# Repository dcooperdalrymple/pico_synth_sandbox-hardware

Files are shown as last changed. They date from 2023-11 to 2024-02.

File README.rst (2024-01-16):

pico_synth_sandbox Hardware
===========================



Raspberry Pi Pico digital synthesizer board with stereo I2S audio (ADC & DAC), stereo omnidirectional MEMS microphones, MIDI i/o, a 16-key capacitive keybed, 1602 display, 2 rotary encoders, and LiPo battery charging and power distribution. Designed for use with CircuitPython and synthio.

.. list-table::

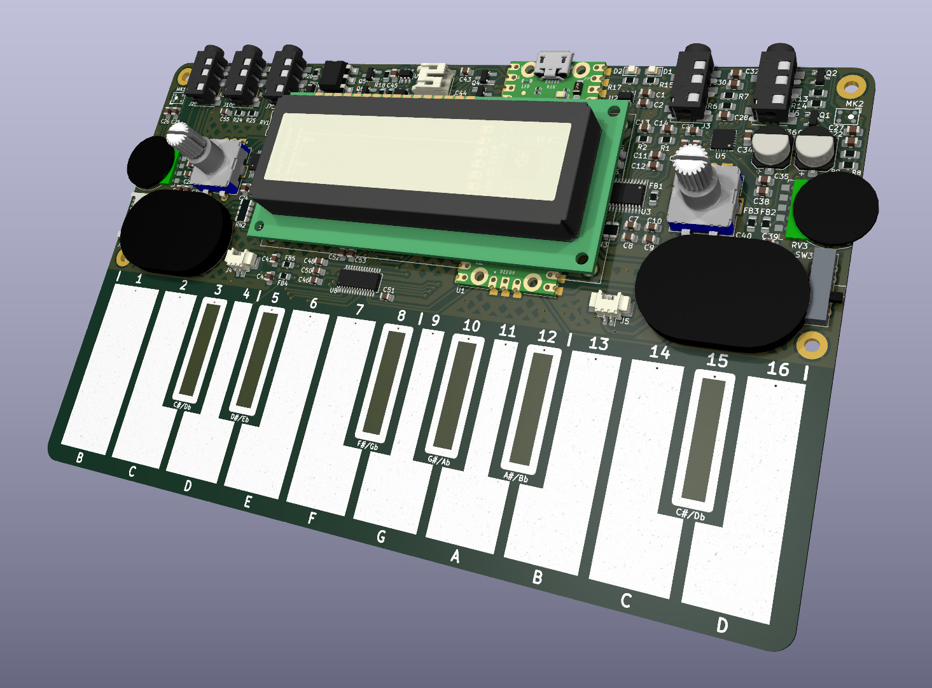
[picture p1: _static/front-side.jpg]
Front view of 3d rendered board
    * - 
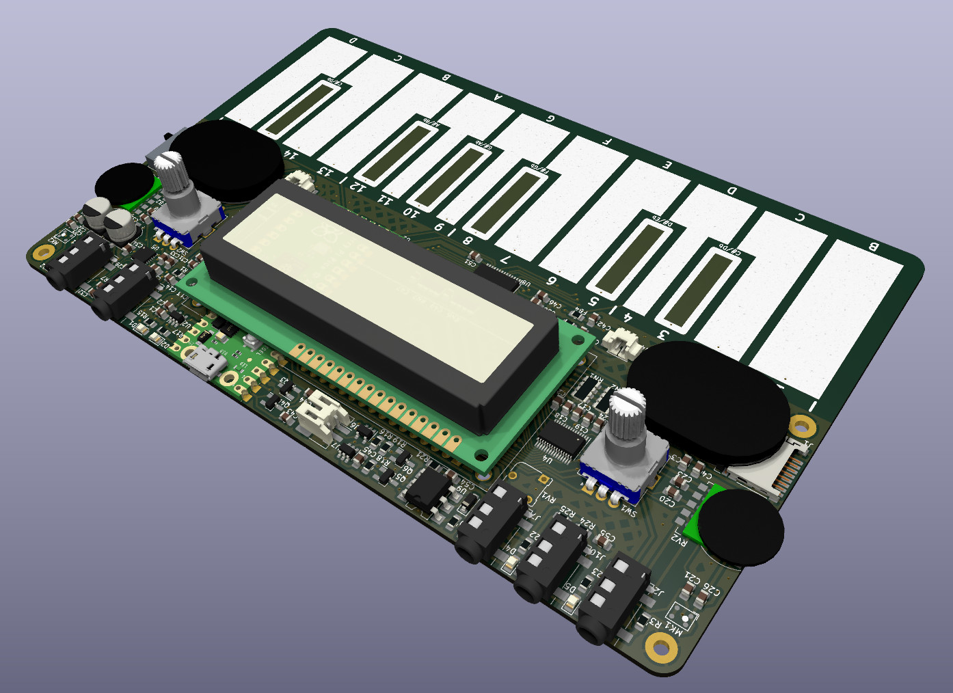
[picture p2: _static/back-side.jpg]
Back view of 3d rendered board
      - 
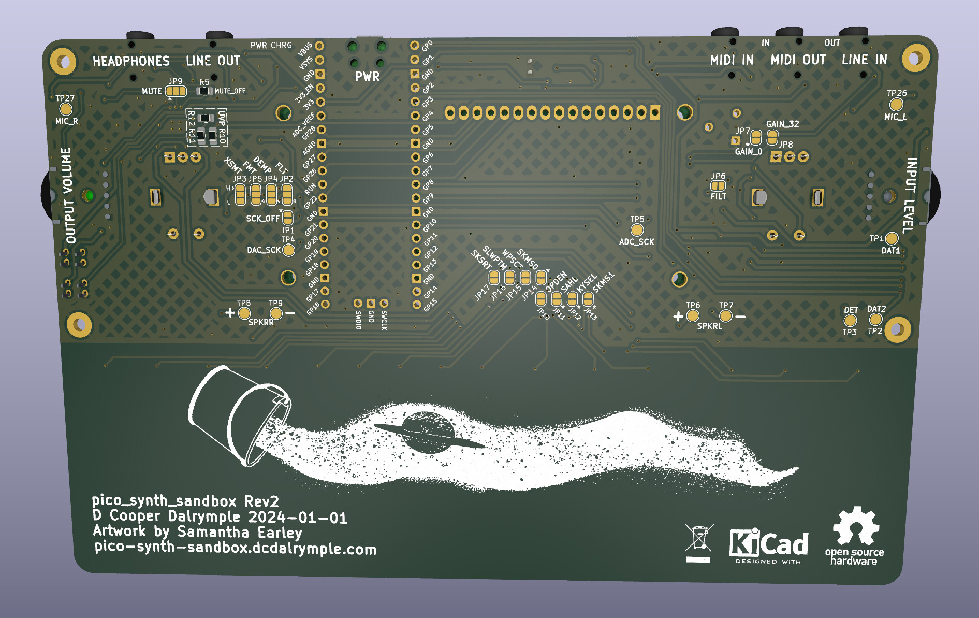
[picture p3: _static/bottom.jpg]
Bottom view of 3d rendered board
      - 

Features
--------

* PCM5102 I2S DAC with line output
* PCM1860 I2S ADC with line and microphone input
* PAM8019 amplifier with stereo class AB headphone and class D speaker output
* LiPo Battery usb charging and power supply controlled by 3v3_enable
* MIDI input and output via MIDI TRS-A 3.5mm jacks (compatible with most adapters)
* Input level potentiometer (line input only)
* Amplifier volume potentiometer (line output not included)
* 16 capacitive sense touch buttons powered by the TTP229-BSF
* 16x2 LCD character display
* 2 rotary encoders with push switches
* Micro SD card storage

Software
--------

CircuitPython Library
~~~~~~~~~~~~~~~~~~~~~

The pico_synth_sandbox is designed for use with CircuitPython and synthio. A specialized library with hardware abstraction and a multitude of additional features for embedded audio synthesis is available in the `pico_synth_sandbox <https://github.com/dcooperdalrymple/pico_synth_sandbox>`_ repository. Library documentation and other resources are available on `Read the Docs <https://pico-synth-sandbox.readthedocs.io/>`_.

CircuitPython Tests
~~~~~~~~~~~~~~~~~~~

A number of hardware tests are available within the ``./tests`` directory to validate the ``pico_synth_sandbox`` hardware using the REPL serial terminal.

RP2040 Pin Assignment
---------------------

Some pins require solder jumper configuration if you do not use the default pin assignment for MIDI & I2S.

.. list-table::
    :header-rows: 1

    * - Pin Reference
      - Assignment
      - Direction
      - Function

    * - GP0
      - SD Card RX
      - Input
      - SPI0
    * - GP1
      - SD Card CS
      - Output
      - SPI0
    * - GP2
      - SD Card SCK
      - Output
      - SPI0
    * - GP3
      - SD Card TX
      - Output
      - SPI0
    * - GP4
      - MIDITX
      - Output
      - UART1
    * - GP5
      - MIDIRX
      - Input
      - UART1
    * - GP6
      - 1602 Enable
      - Output
      - GPIO
    * - GP7
      - 1602 Reset
      - Output
      - GPIO
    * - GP8
      - ADC Serial Clock
      - Output
      - I2S
    * - GP9
      - ADC Word Select
      - Output
      - I2S
    * - GP10
      - ADC Serial Data
      - Input
      - I2S
    * - GP11
      - Encoder 1 A
      - Input
      - GPIO
    * - GP12
      - Encoder 1 B
      - Input
      - GPIO
    * - GP13
      - Encoder 1 Switch
      - Input
      - GPIO
    * - GP14
      - TTP229 Serial Data
      - Input
      - GPIO
    * - GP15
      - TTP229 Serial Clock
      - Output
      - GPIO
    * - GP16
      - Encoder 2 A
      - Input
      - GPIO
    * - GP17
      - Encoder 2 B
      - Input
      - GPIO
    * - GP18
      - Encoder 2 Switch
      - Input
      - GPIO
    * - GP19
      - DAC Serial Clock
      - Output
      - I2S
    * - GP20
      - DAC Word Select
      - Output
      - I2S
    * - GP21
      - DAC Serial Data
      - Output
      - I2S
    * - GP22
      - 1602 D4
      - Output
      - GPIO
    * - GP26
      - 1602 D5
      - Output
      - GPIO
    * - GP27
      - 1602 D6
      - Output
      - GPIO
    * - GP28
      - 1602 D7
      - Output
      - GPIO

Schematic
---------

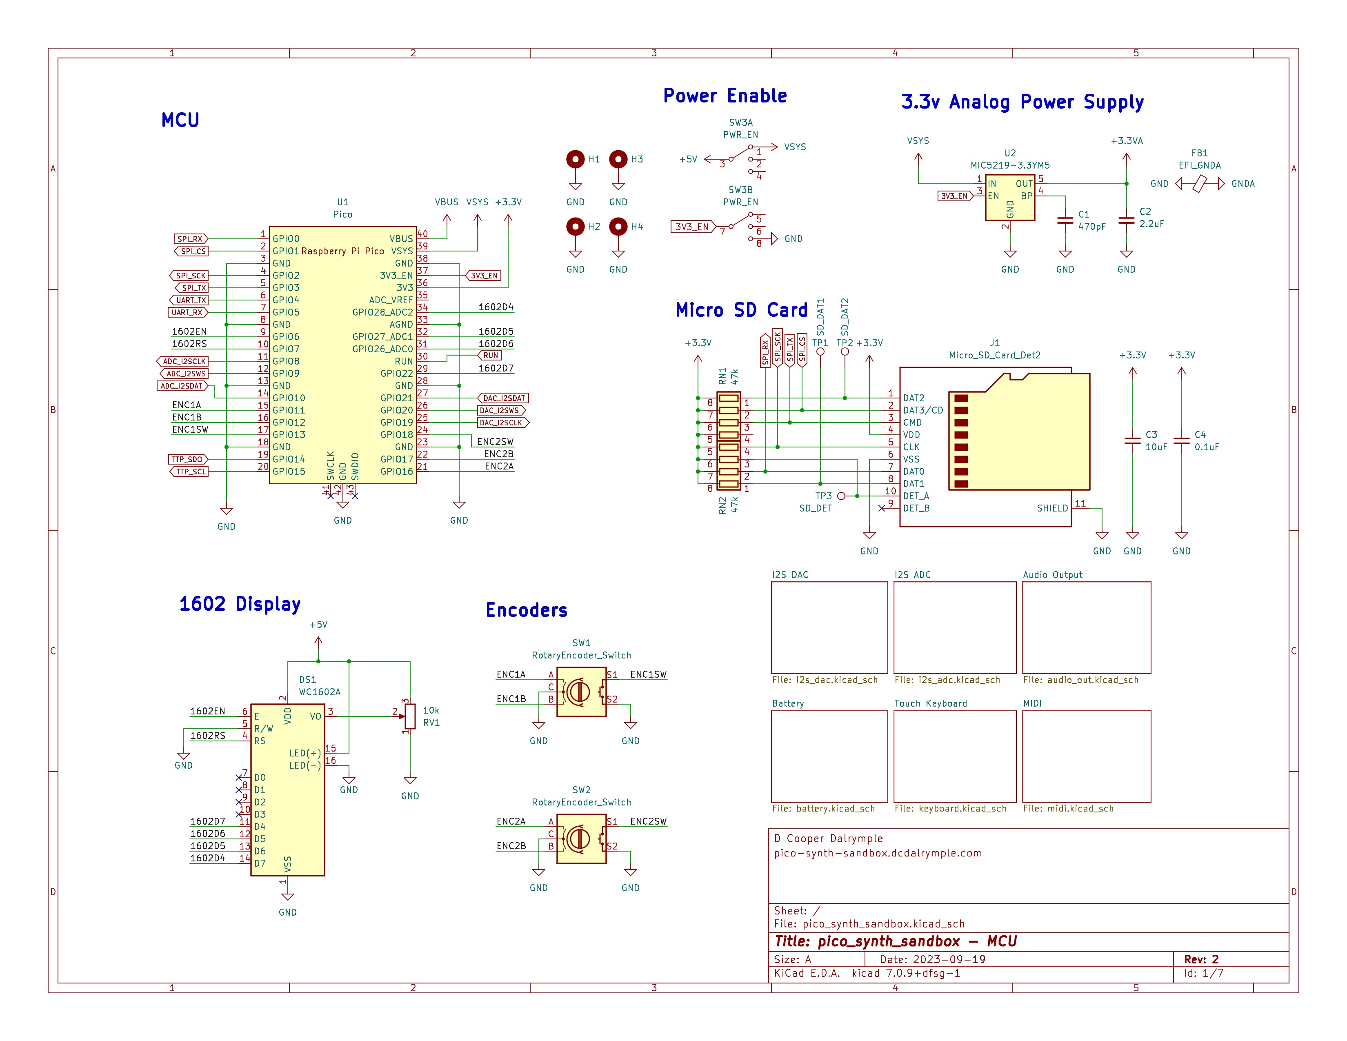
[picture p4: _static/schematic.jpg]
Hardware schematic of pico_synth_sandbox device


Attribution
-----------

* Project inspired by `todbot/pico_test_synth <https://github.com/todbot/pico_test_synth>`_

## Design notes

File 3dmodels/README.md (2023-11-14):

# KiCAD 3D Models
Most models were sourced from GrabCAD and weren't given proper attribution. These files were for temporary use in order to generate preview renders. They will likely be removed in a future update.

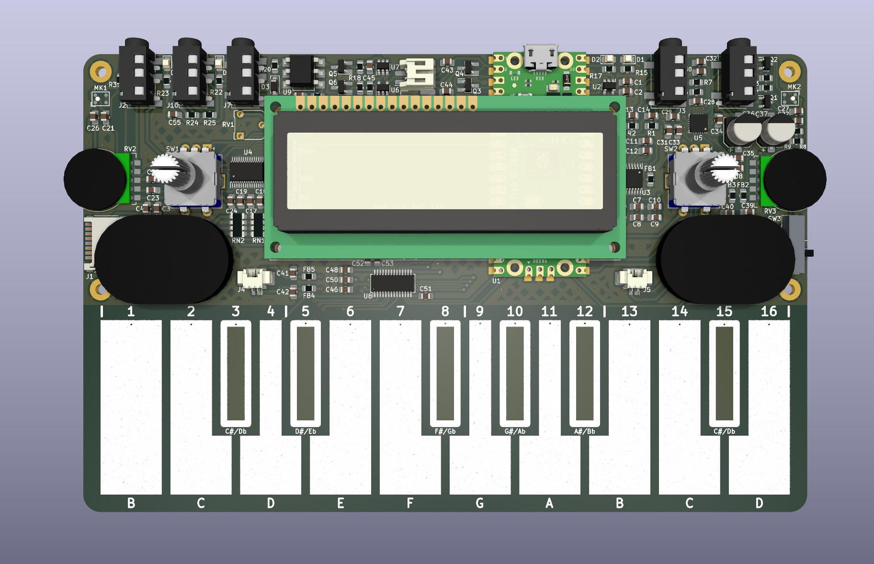
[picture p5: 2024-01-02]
_static/top.jpg

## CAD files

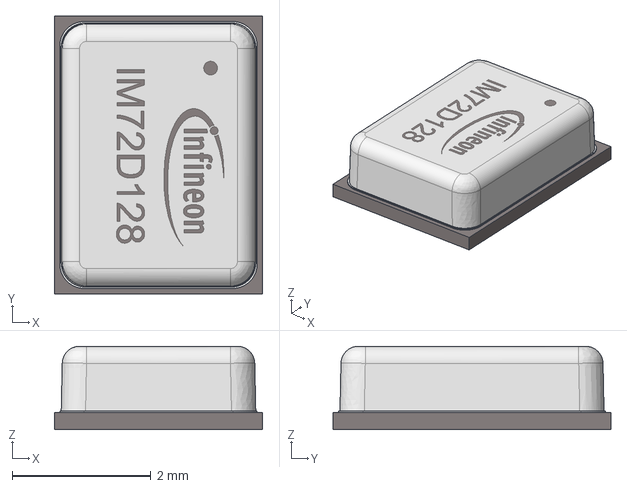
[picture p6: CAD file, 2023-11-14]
3dmodels/digital-microphone-1/IM72D128 MEMS microphone.stp
3.00 x 4.00 x 1.20 mm

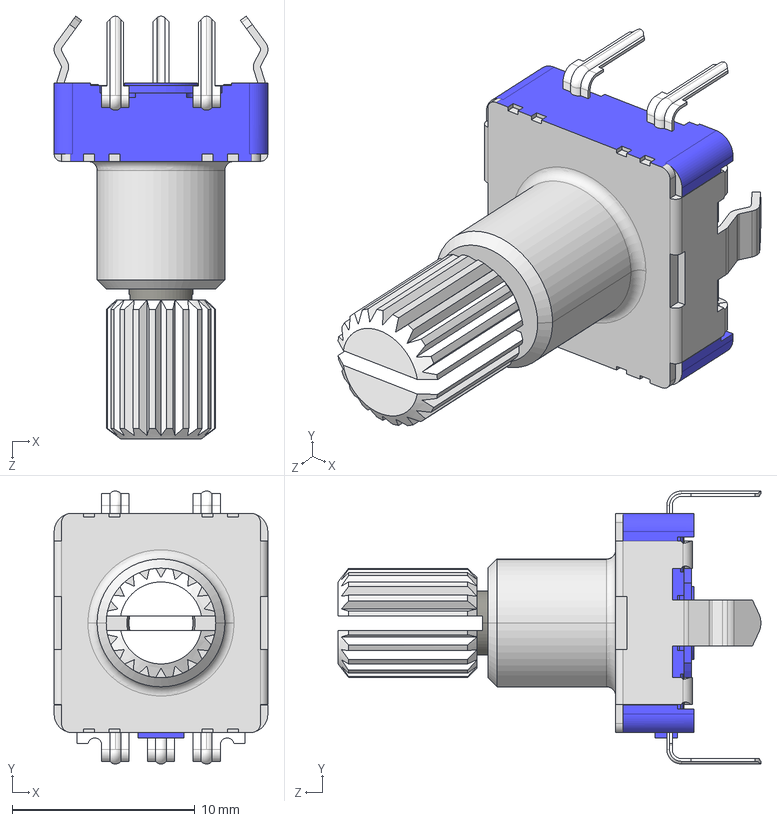
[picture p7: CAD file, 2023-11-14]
3dmodels/ec11-encoder/EC11 Rotary Encoder Dode Switch-15mm .STEP
11.7 x 15.0 x 23.2 mm

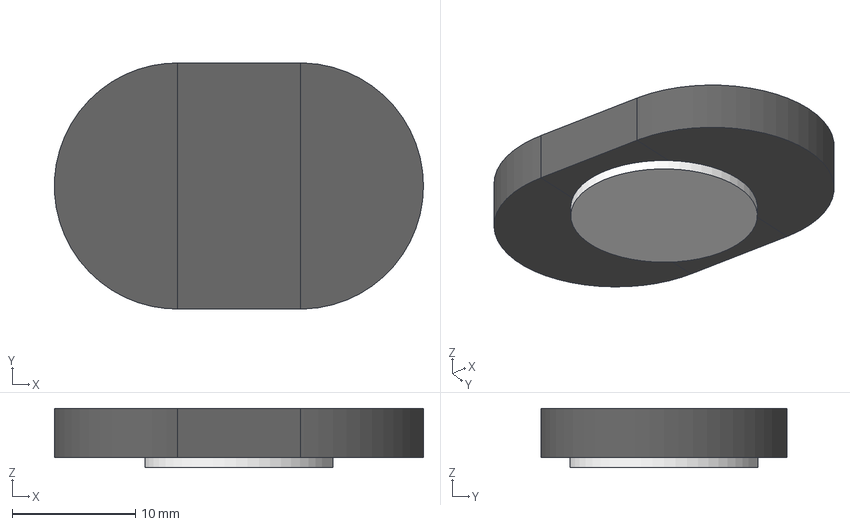
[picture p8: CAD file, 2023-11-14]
3dmodels/mini-oval-speaker-with-short-wires-8-ohm-1-watt/mini-oval-speaker.step
30.0 x 20.0 x 4.80 mm

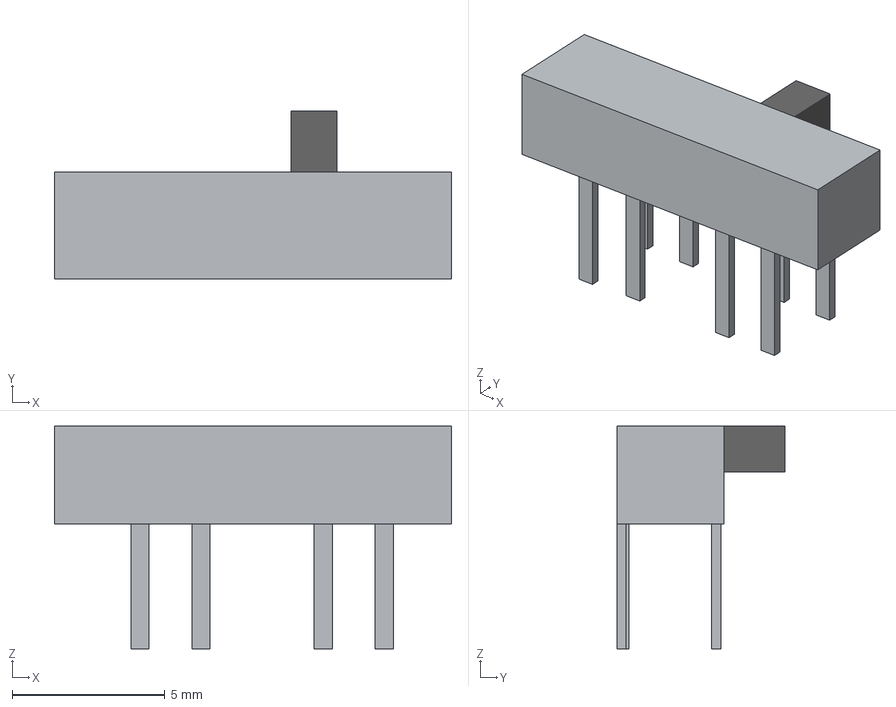
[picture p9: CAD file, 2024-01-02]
3dmodels/MK-23D38/MK-23D38.step
13.0 x 5.50 x 7.30 mm

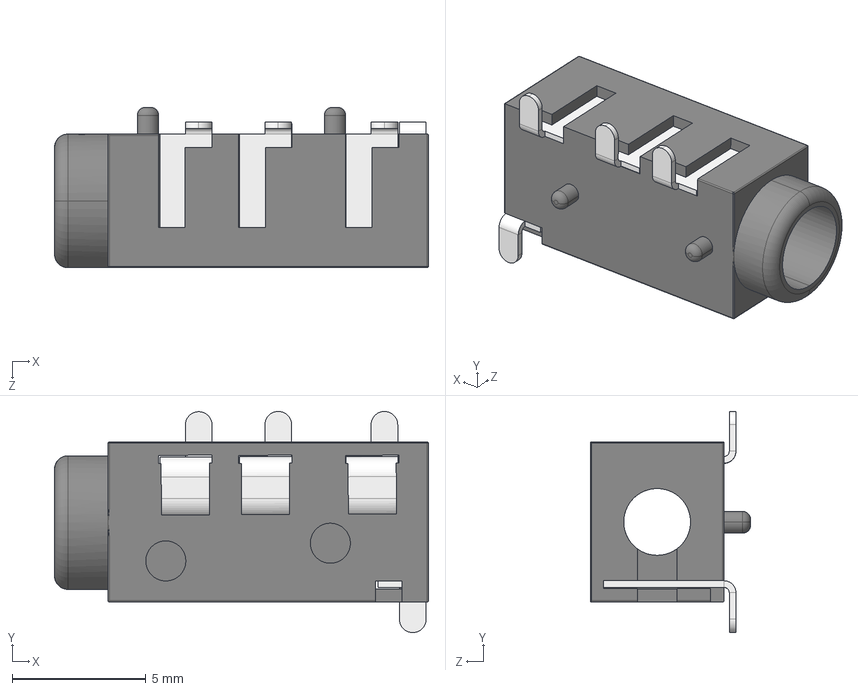
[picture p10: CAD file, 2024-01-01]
3dmodels/PJ320D/PJ320D.STEP
14.0 x 8.28 x 6.00 mm
PJ320A
PJ320D-Pin x 3
PJ320D-Pin-B

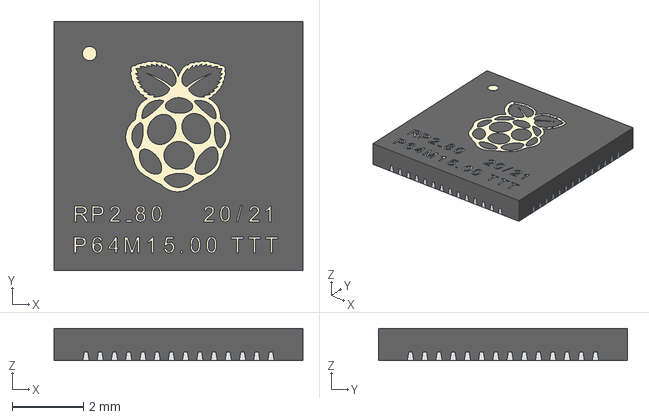
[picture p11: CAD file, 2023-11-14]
3dmodels/raspberry-pi-pico/RP2040.step
7.00 x 7.00 x 0.91 mm

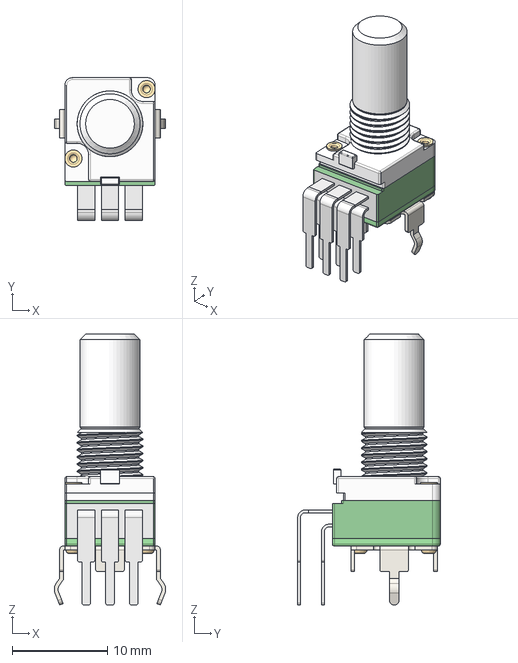
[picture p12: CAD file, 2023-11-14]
3dmodels/RD902F-40-00D/RD902F-40-00D.stp
11.7 x 15.0 x 28.5 mm

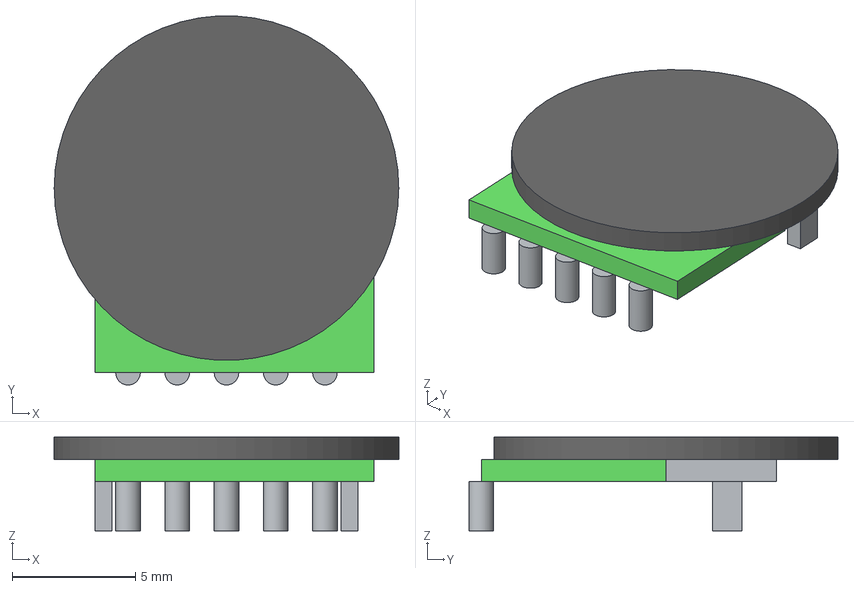
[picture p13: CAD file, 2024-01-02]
3dmodels/RK10J12R0A0B/RK10J12R0A0B.step
14.0 x 15.0 x 3.80 mm

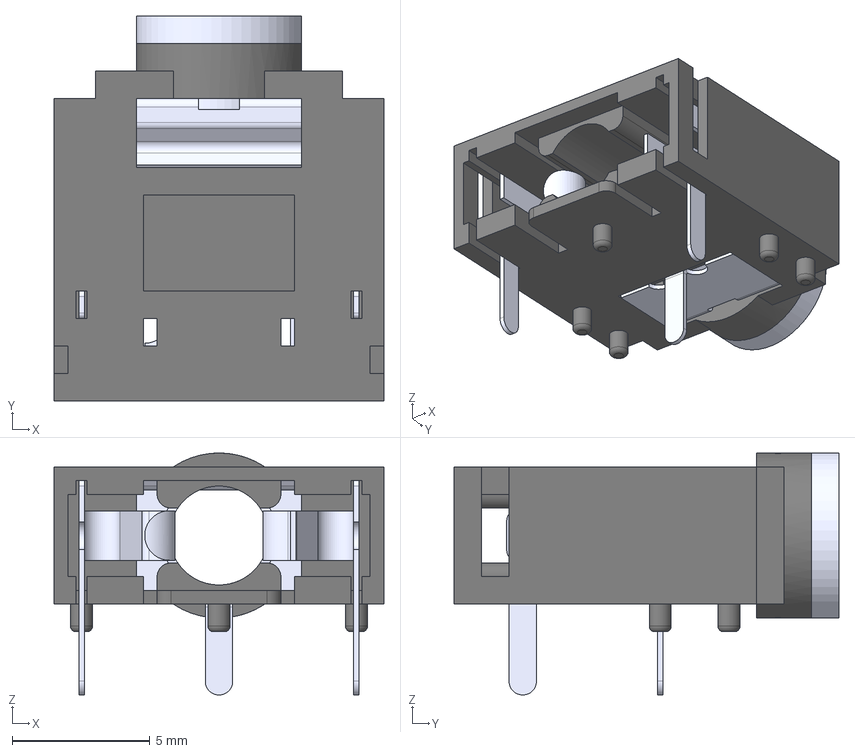
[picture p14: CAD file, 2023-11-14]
3dmodels/SJ1-3525N/ST-111.step
12.0 x 14.0 x 8.80 mm

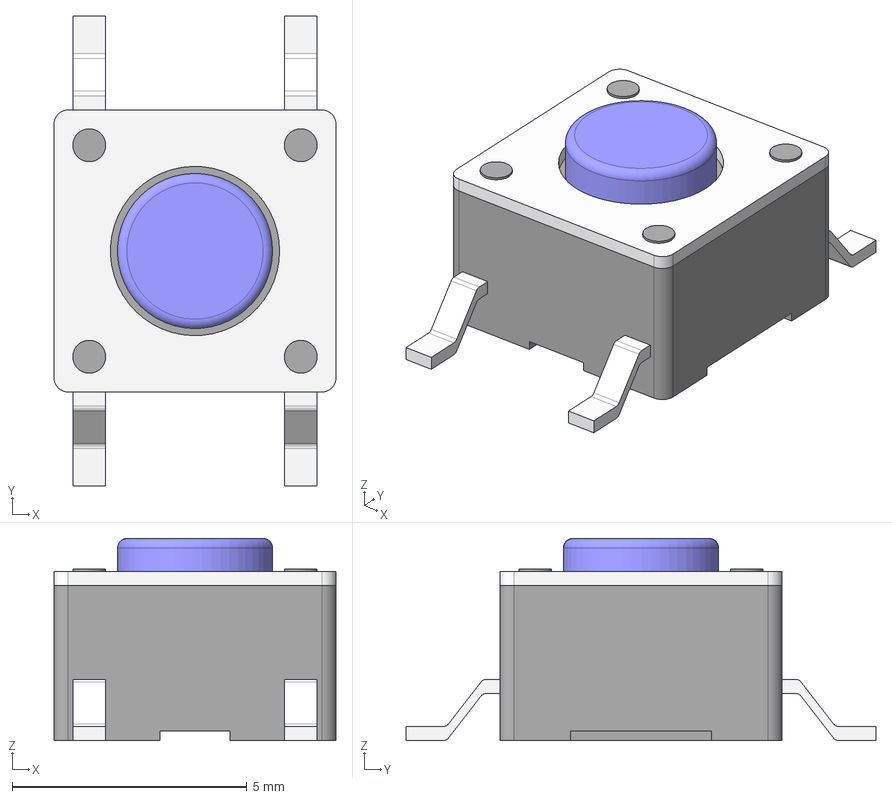
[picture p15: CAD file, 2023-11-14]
3dmodels/smd-button/LL3301_SMT Button.FCStd
6.00 x 10.0 x 4.30 mm
TopPlate
Plunger
Pins

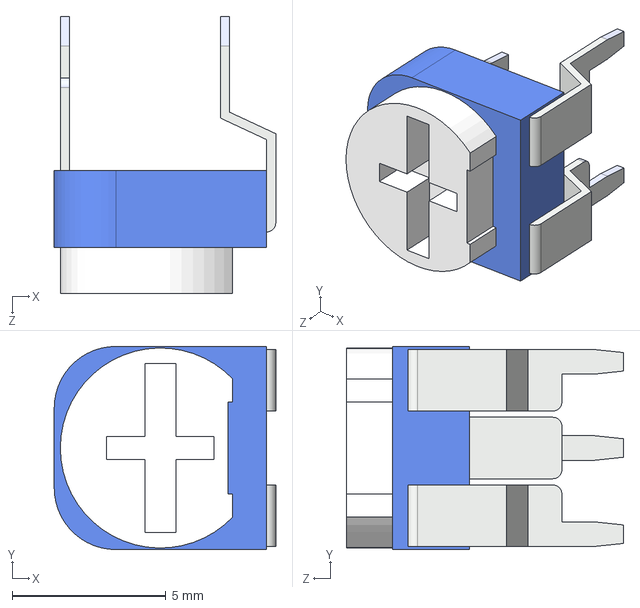
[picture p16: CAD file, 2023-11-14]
3dmodels/trimpot/Potentiometer Blue.STEP
7.20 x 6.60 x 9.00 mm

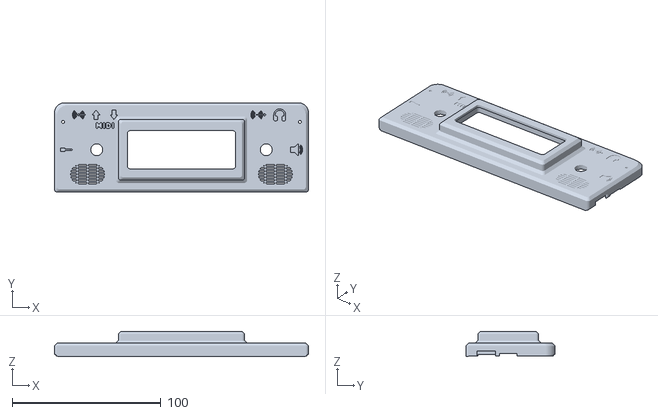
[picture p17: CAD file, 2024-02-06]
case/rev2/pico_synth_sandbox-Rev2-Top.stl
171.0 x 60.0 x 17.1

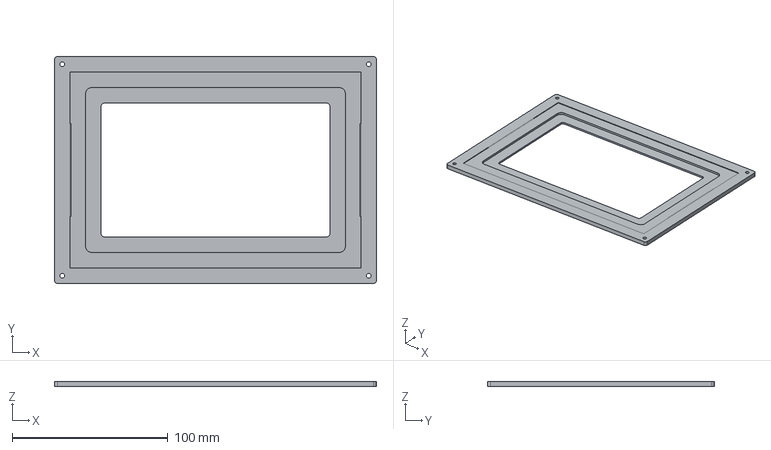
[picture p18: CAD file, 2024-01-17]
stencil-jig/pico_synth_sandbox-StencilJig.FCStd
207.0 x 146.0 x 3.50 mm

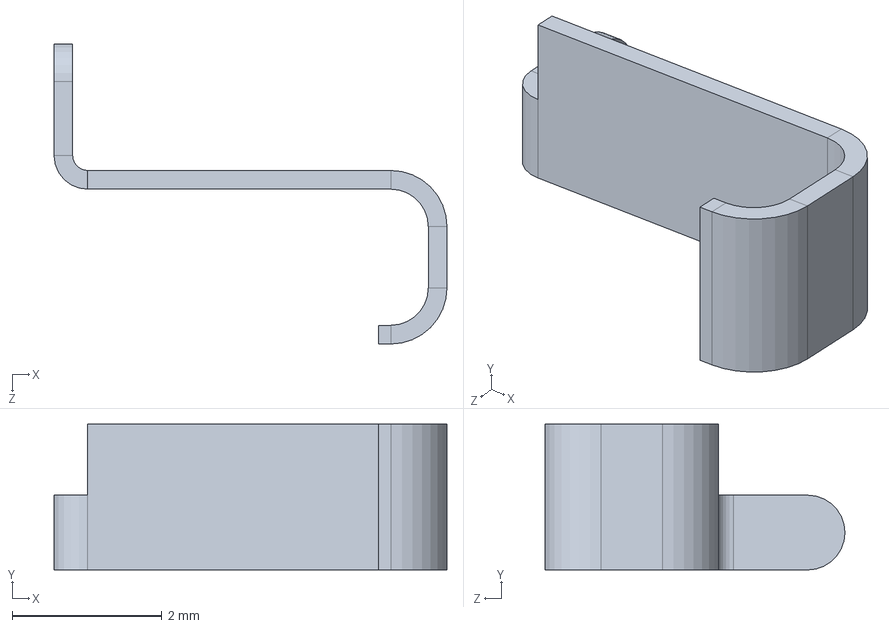
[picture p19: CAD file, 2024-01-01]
3dmodels/PJ320D/PJ320D-Pin.SLDPRT
5.25 x 1.95 x 4.01 mm

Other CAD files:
3dmodels/raspberry-pi-pico/RT6150B-33GQW.step
3dmodels/SJ1-3525N/ST-212.step
3dmodels/smd-button/LL3301_SMD_Button.step
case/rev2/pico_synth_sandbox-Rev2-Bottom.stl
3dmodels/MK-23D38/MK-23D38.FCStd
3dmodels/MK-23D38/MK-23D38.stl
3dmodels/PJ320D/PJ320A.SLDPRT
3dmodels/PJ320D/PJ320D-Pin-B.SLDPRT
3dmodels/PJ320D/PJ320D.SLDASM
3dmodels/RD902F-40-00D/RD902F-40-00D.f3d
3dmodels/RK10J12R0A0B/RK10J12R0A0B.FCStd
3dmodels/RK10J12R0A0B/RK10J12R0A0B.stl
3dmodels/mini-oval-speaker-with-short-wires-8-ohm-1-watt/mini-oval-speaker.FCStd
3dmodels/raspberry-pi-pico/C0603.step
3dmodels/raspberry-pi-pico/C1005.step
3dmodels/raspberry-pi-pico/C2012.step
3dmodels/raspberry-pi-pico/CircuitBoard_Raspberry Pi Pico.step
3dmodels/raspberry-pi-pico/CrystalUnit.step
3dmodels/raspberry-pi-pico/Inductor.step
3dmodels/raspberry-pi-pico/LED1608_t4.step
3dmodels/raspberry-pi-pico/R0603.step
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

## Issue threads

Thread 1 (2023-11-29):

Website is not working

andypiper, 2023-11-29:
Raising an issue here in an effort to let you know that https://pico-synth-sandbox.dcdalrymple.com/ is currently reporting a WordPress error (and the project has just been shared on the Make magazine news feed, so I’m likely not the only one hitting the issue…)

looking forward to learning more about the board when the site is back!

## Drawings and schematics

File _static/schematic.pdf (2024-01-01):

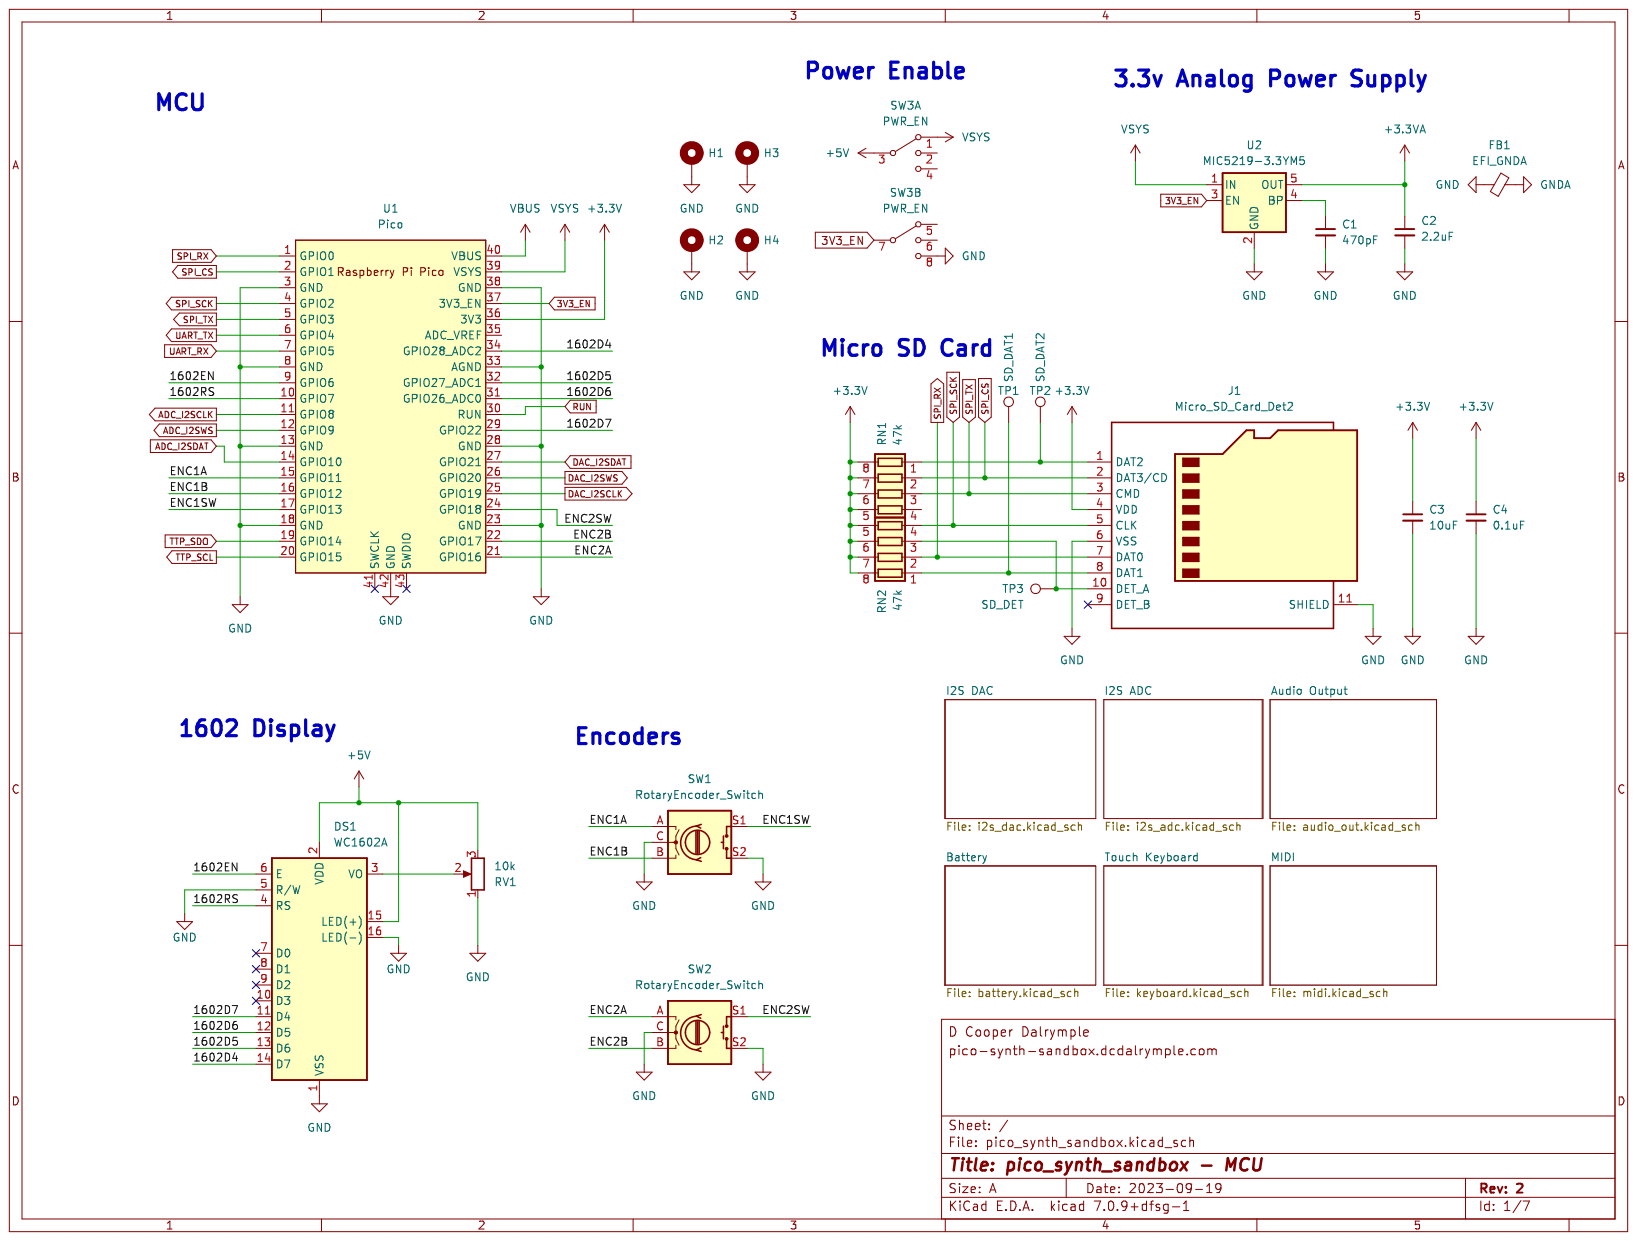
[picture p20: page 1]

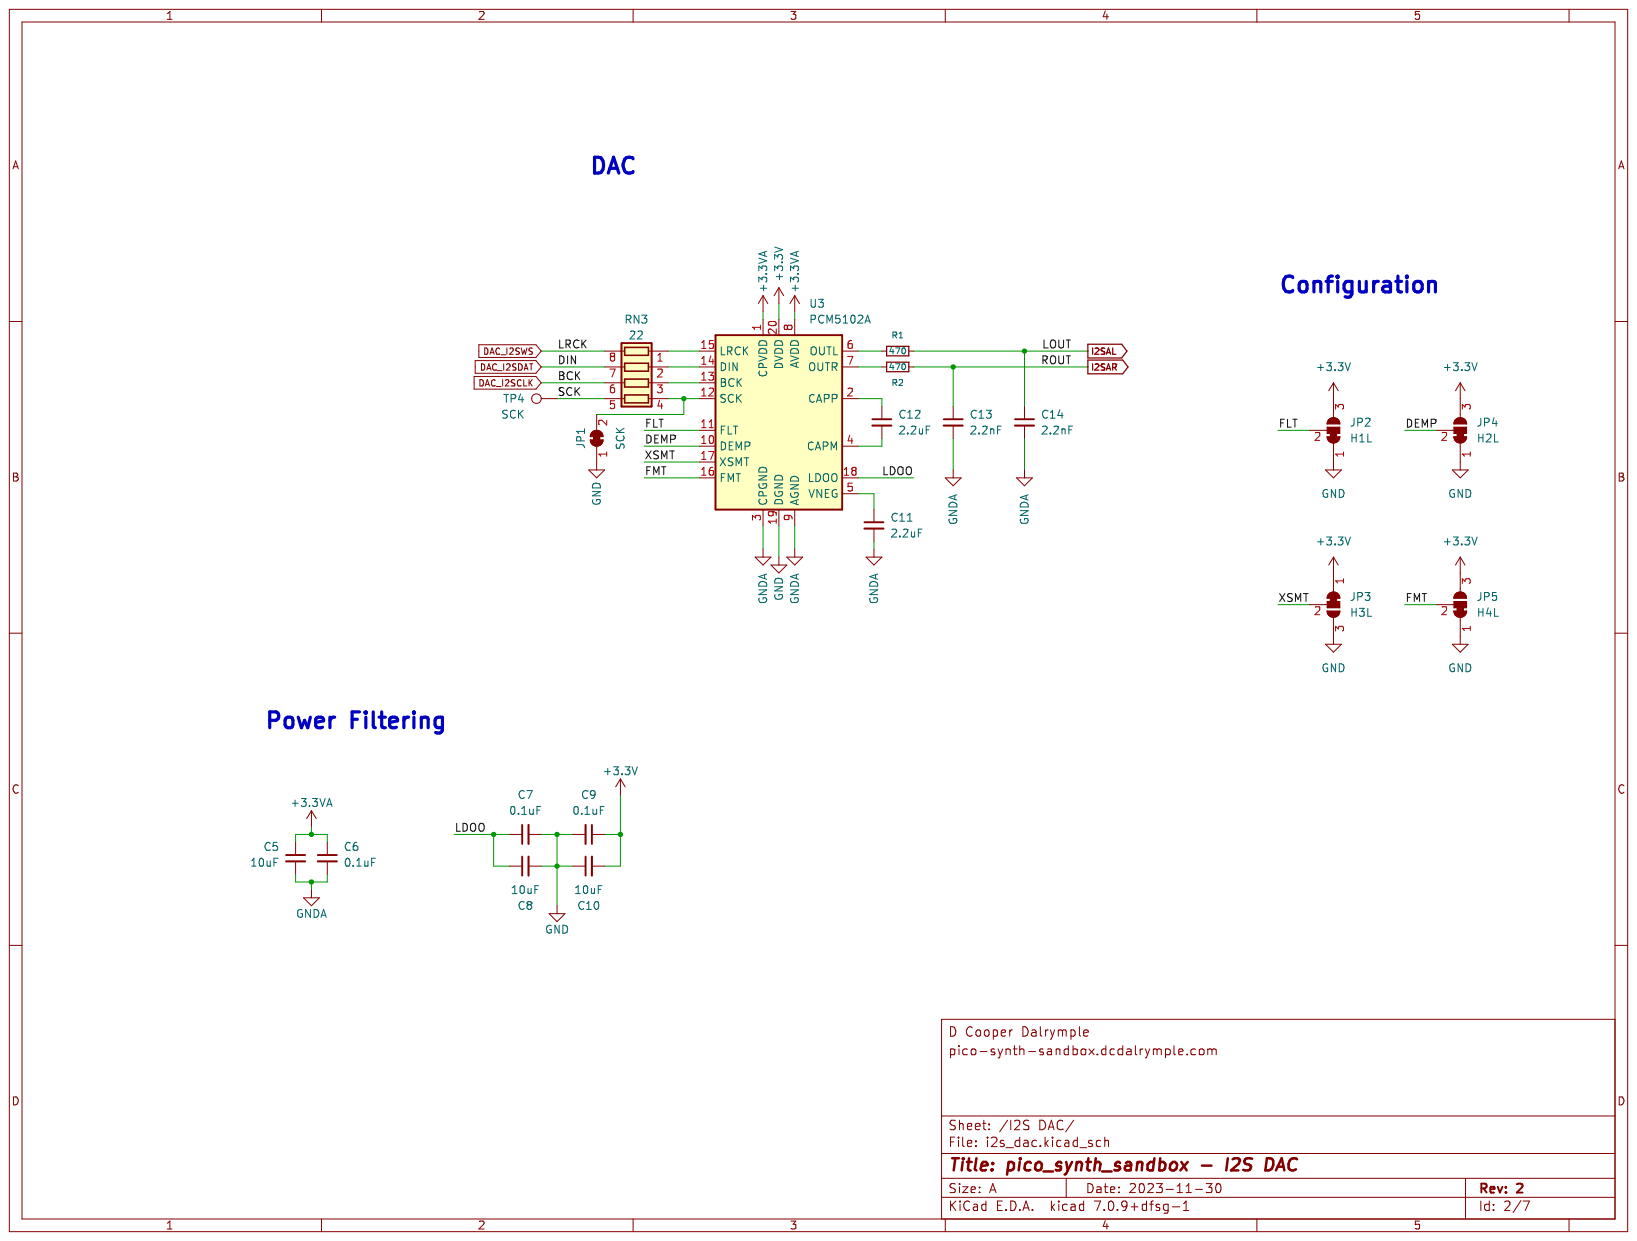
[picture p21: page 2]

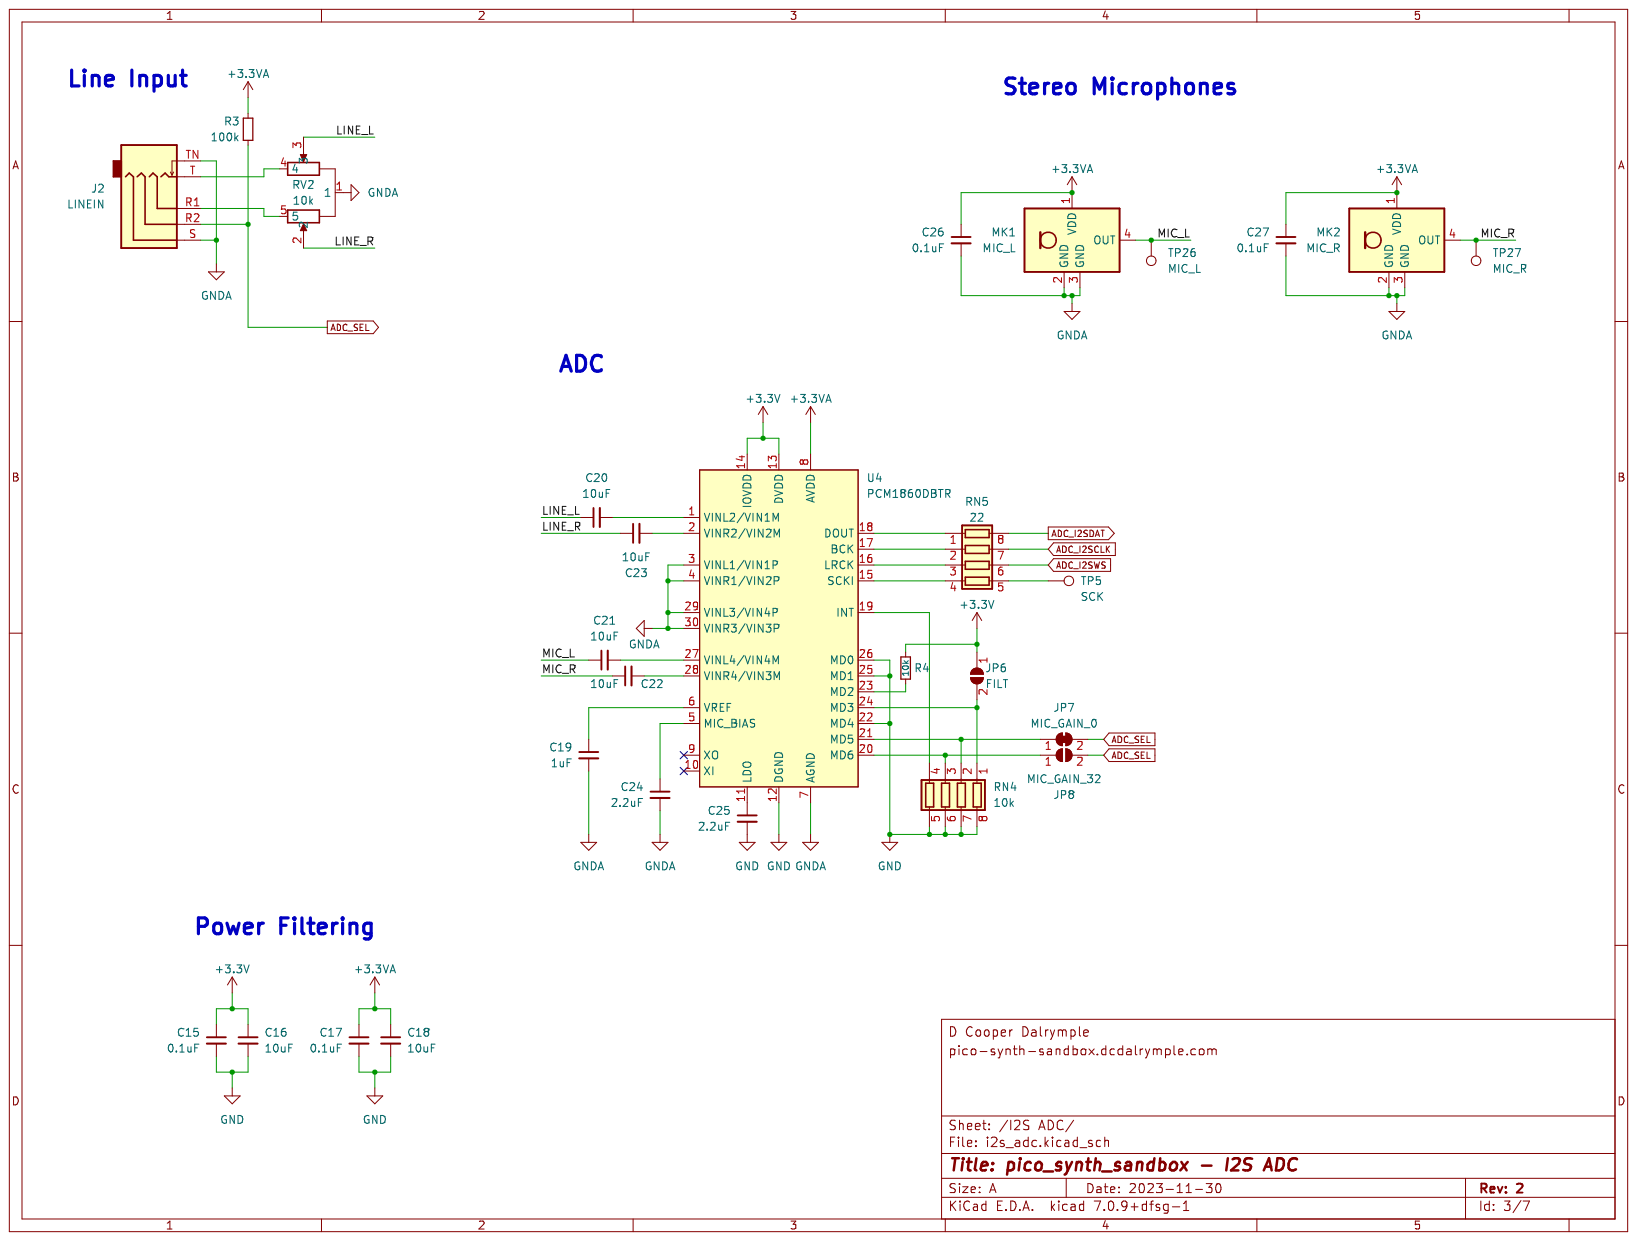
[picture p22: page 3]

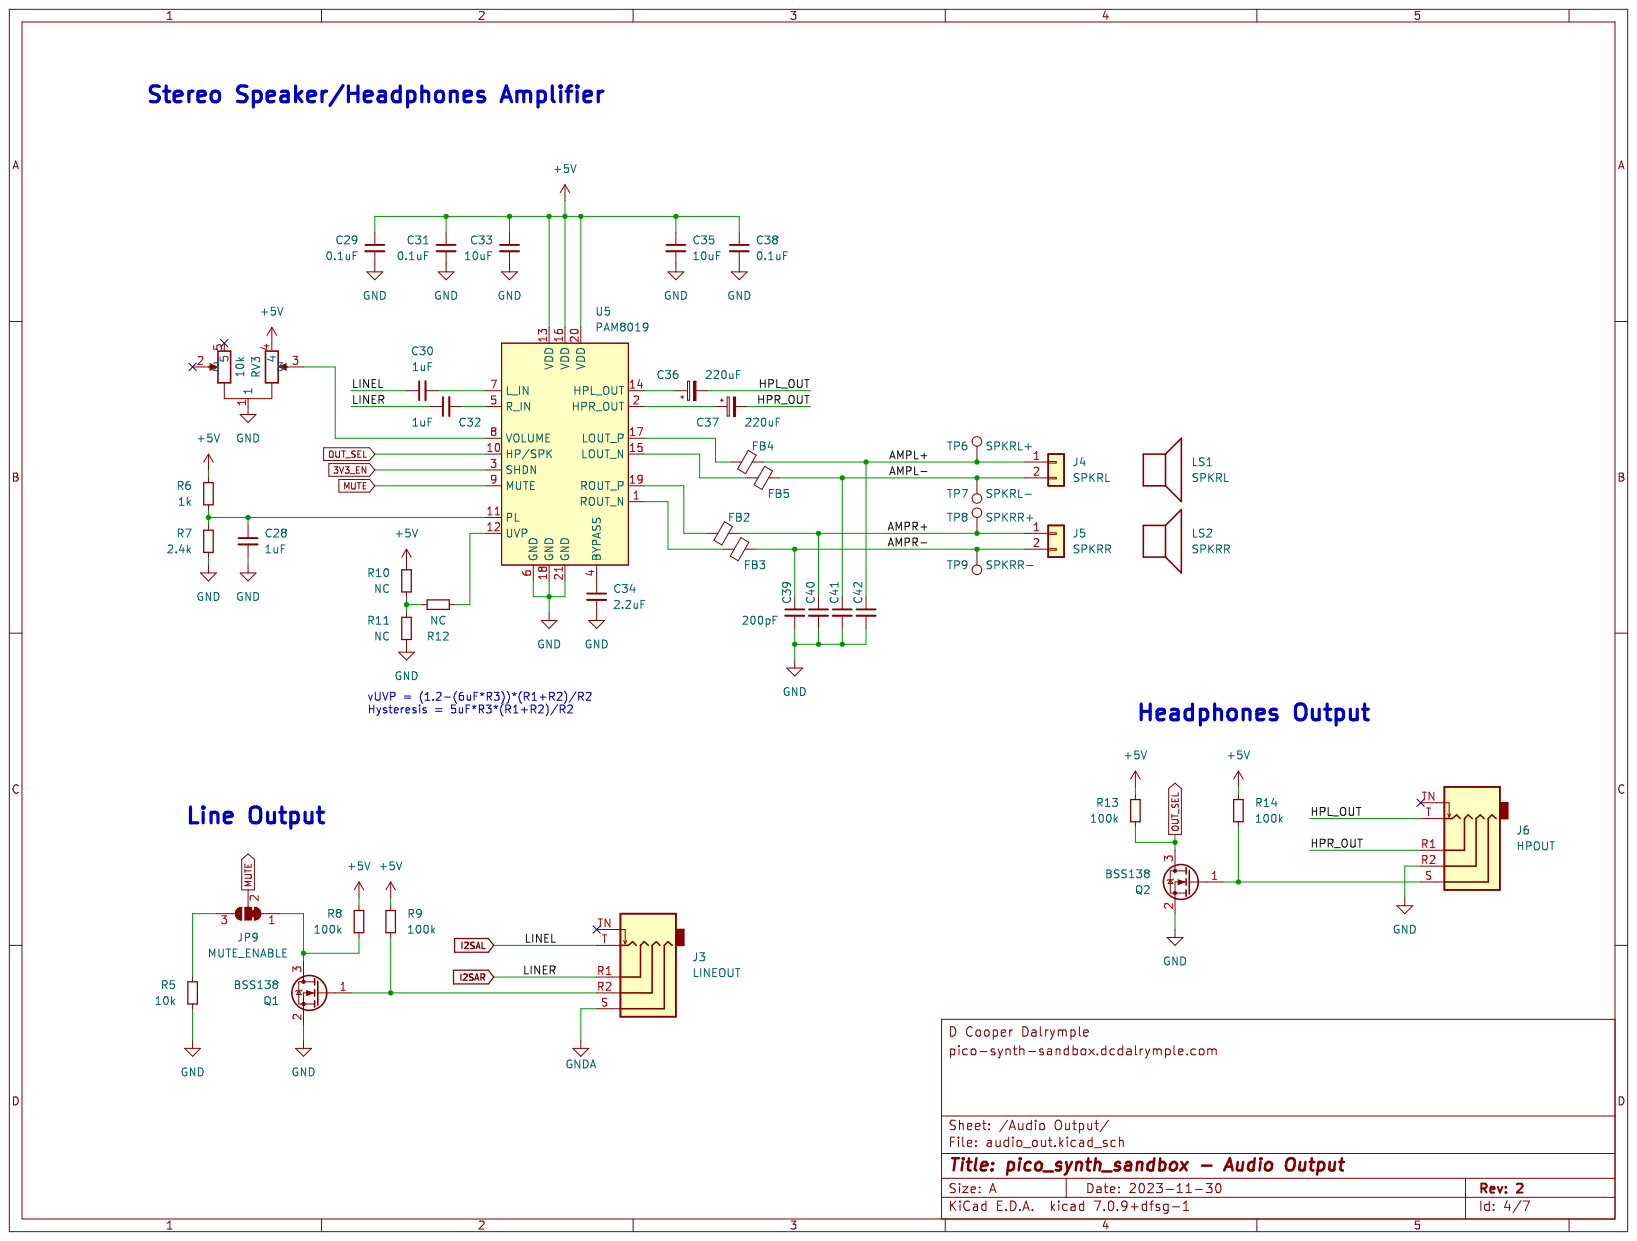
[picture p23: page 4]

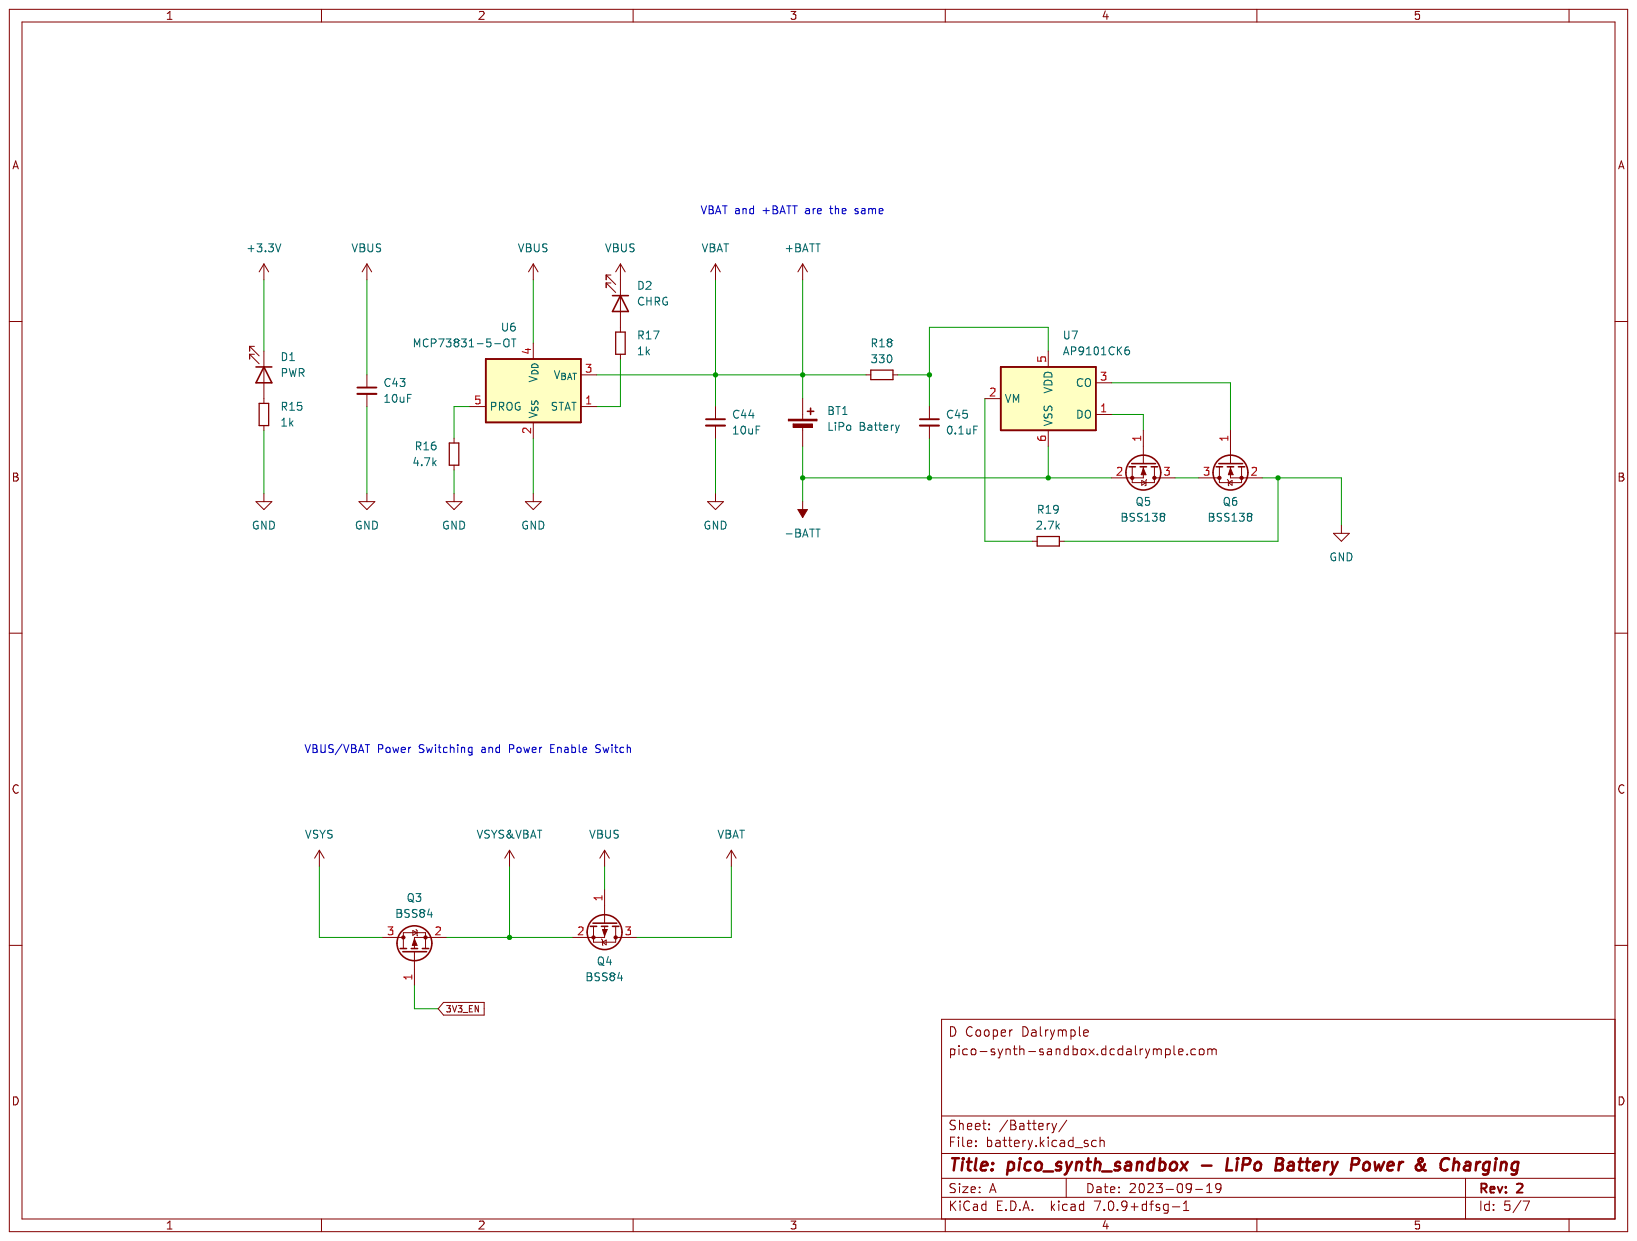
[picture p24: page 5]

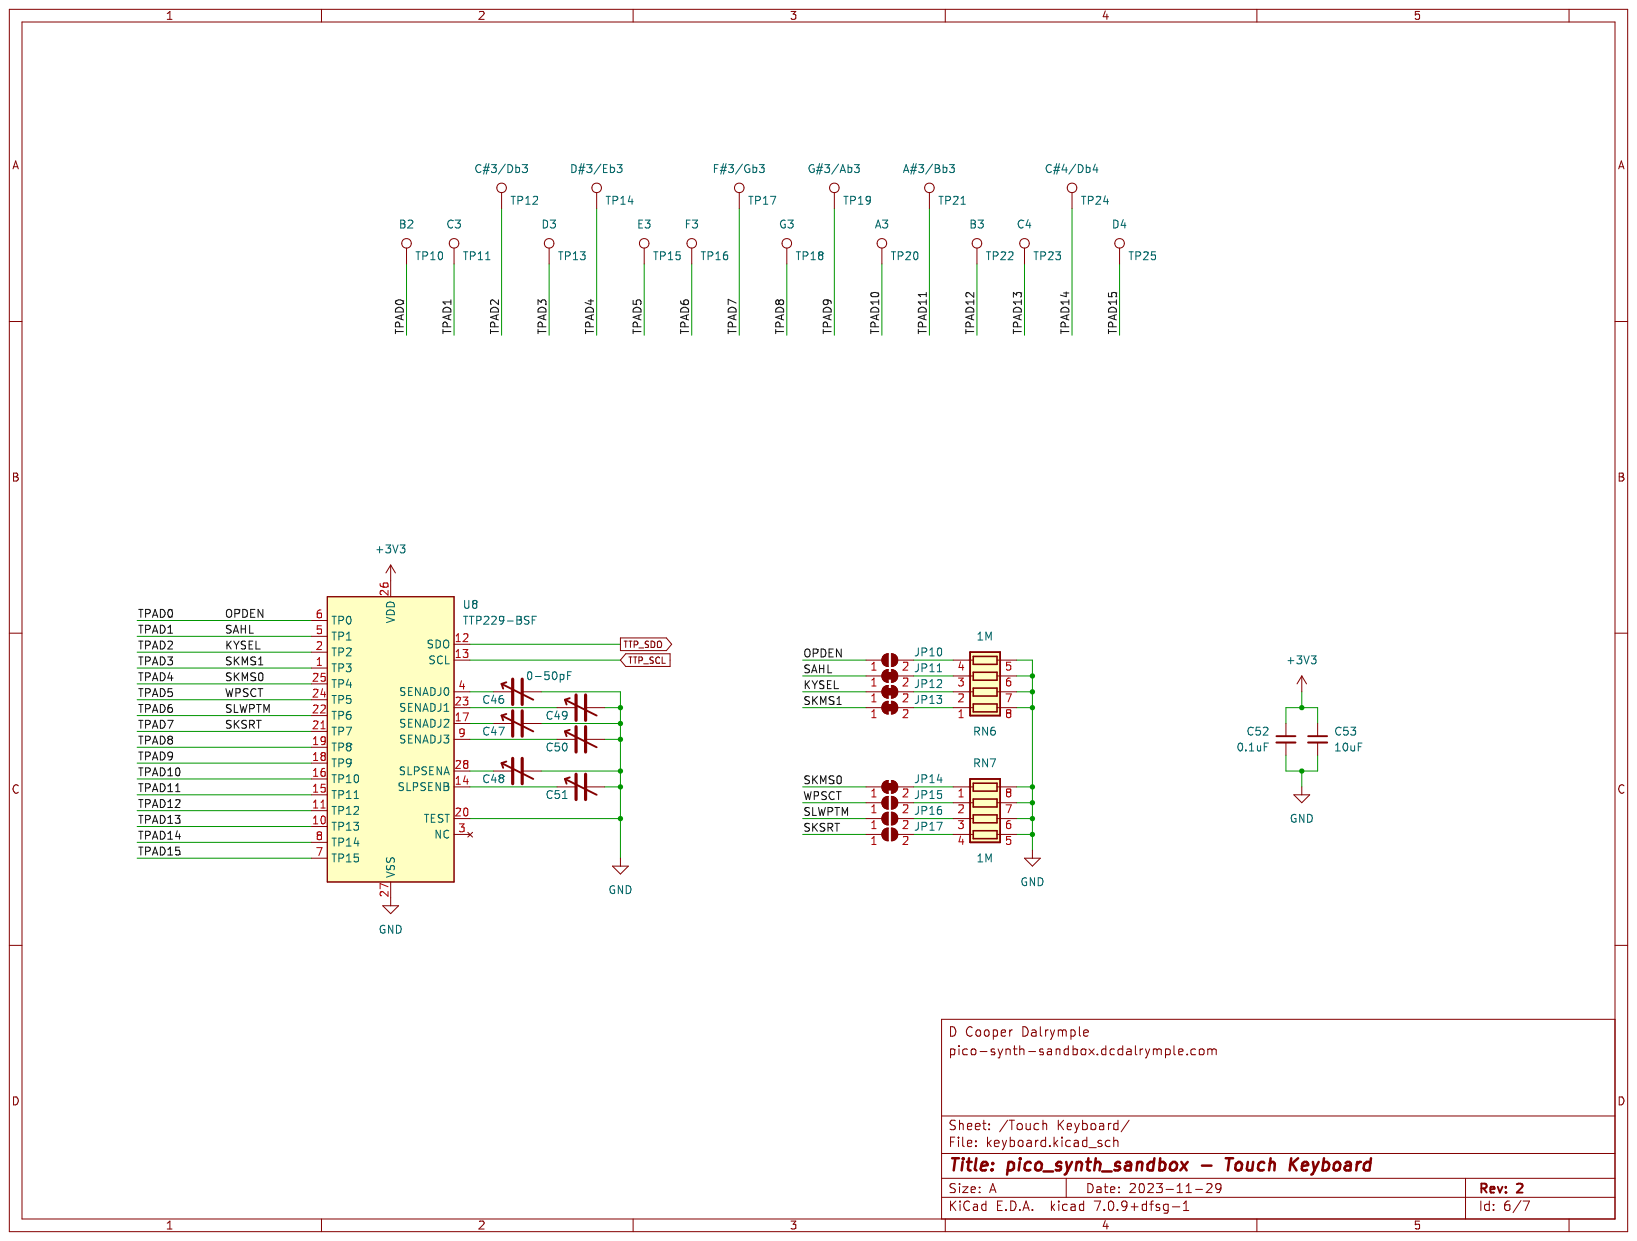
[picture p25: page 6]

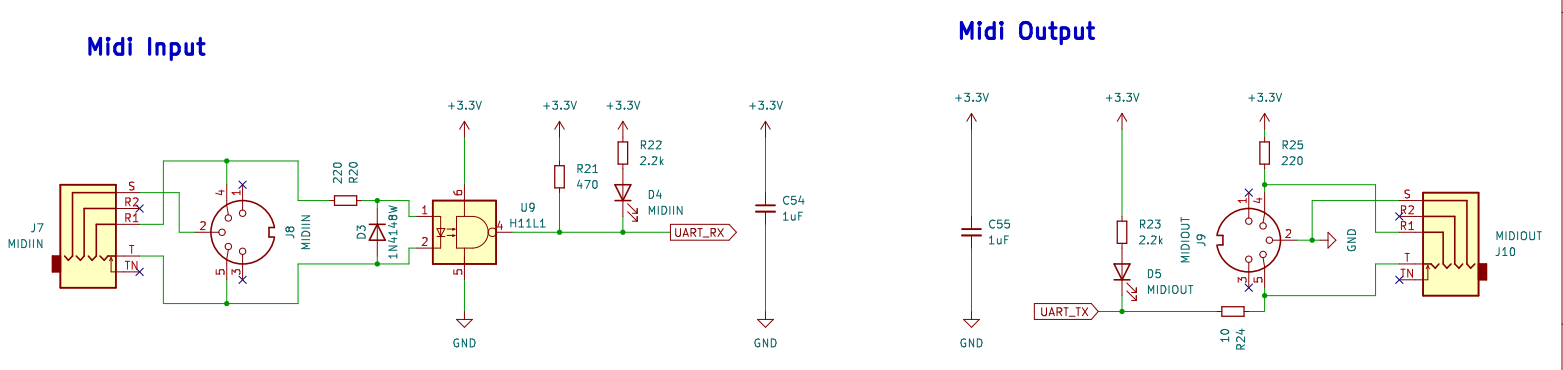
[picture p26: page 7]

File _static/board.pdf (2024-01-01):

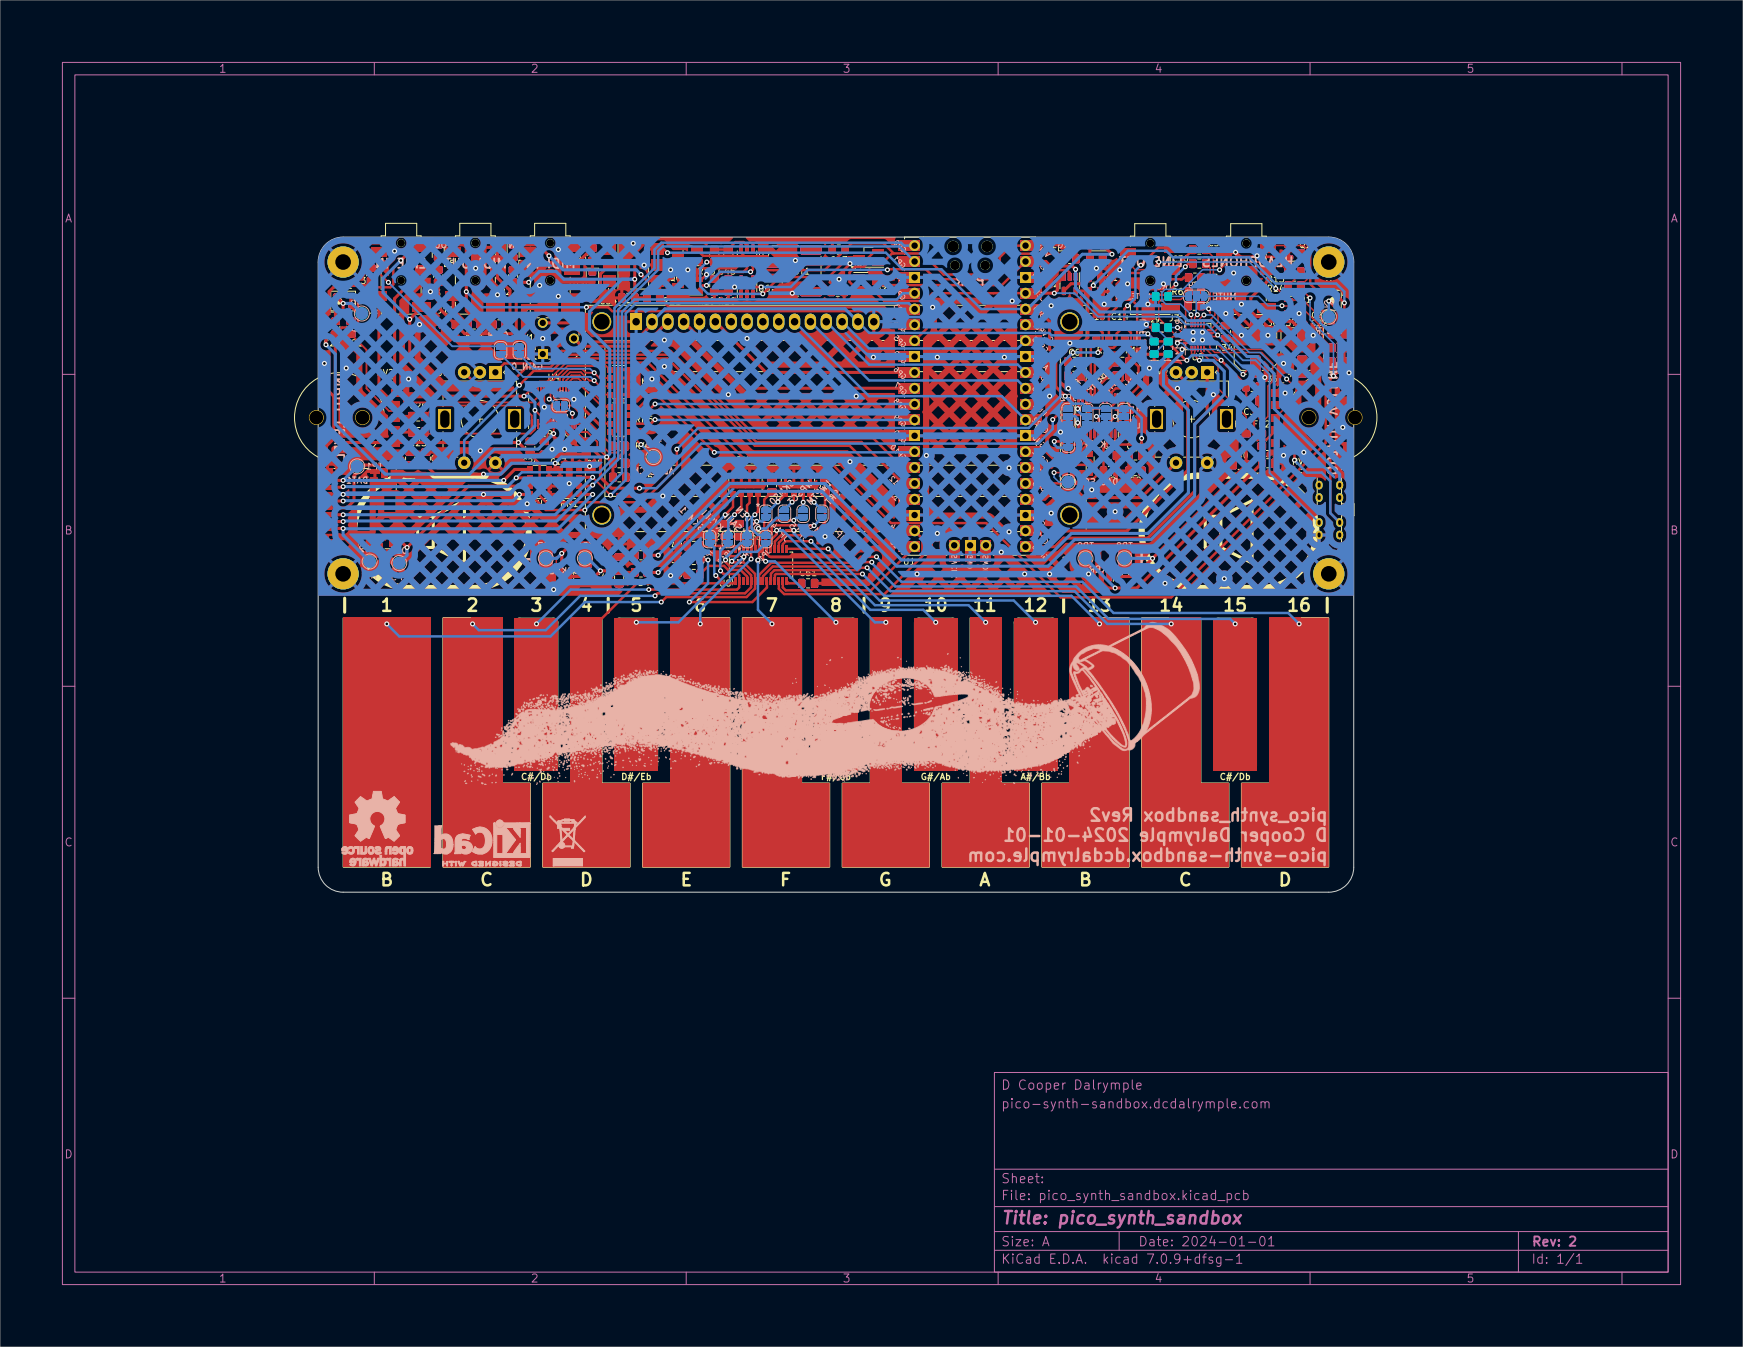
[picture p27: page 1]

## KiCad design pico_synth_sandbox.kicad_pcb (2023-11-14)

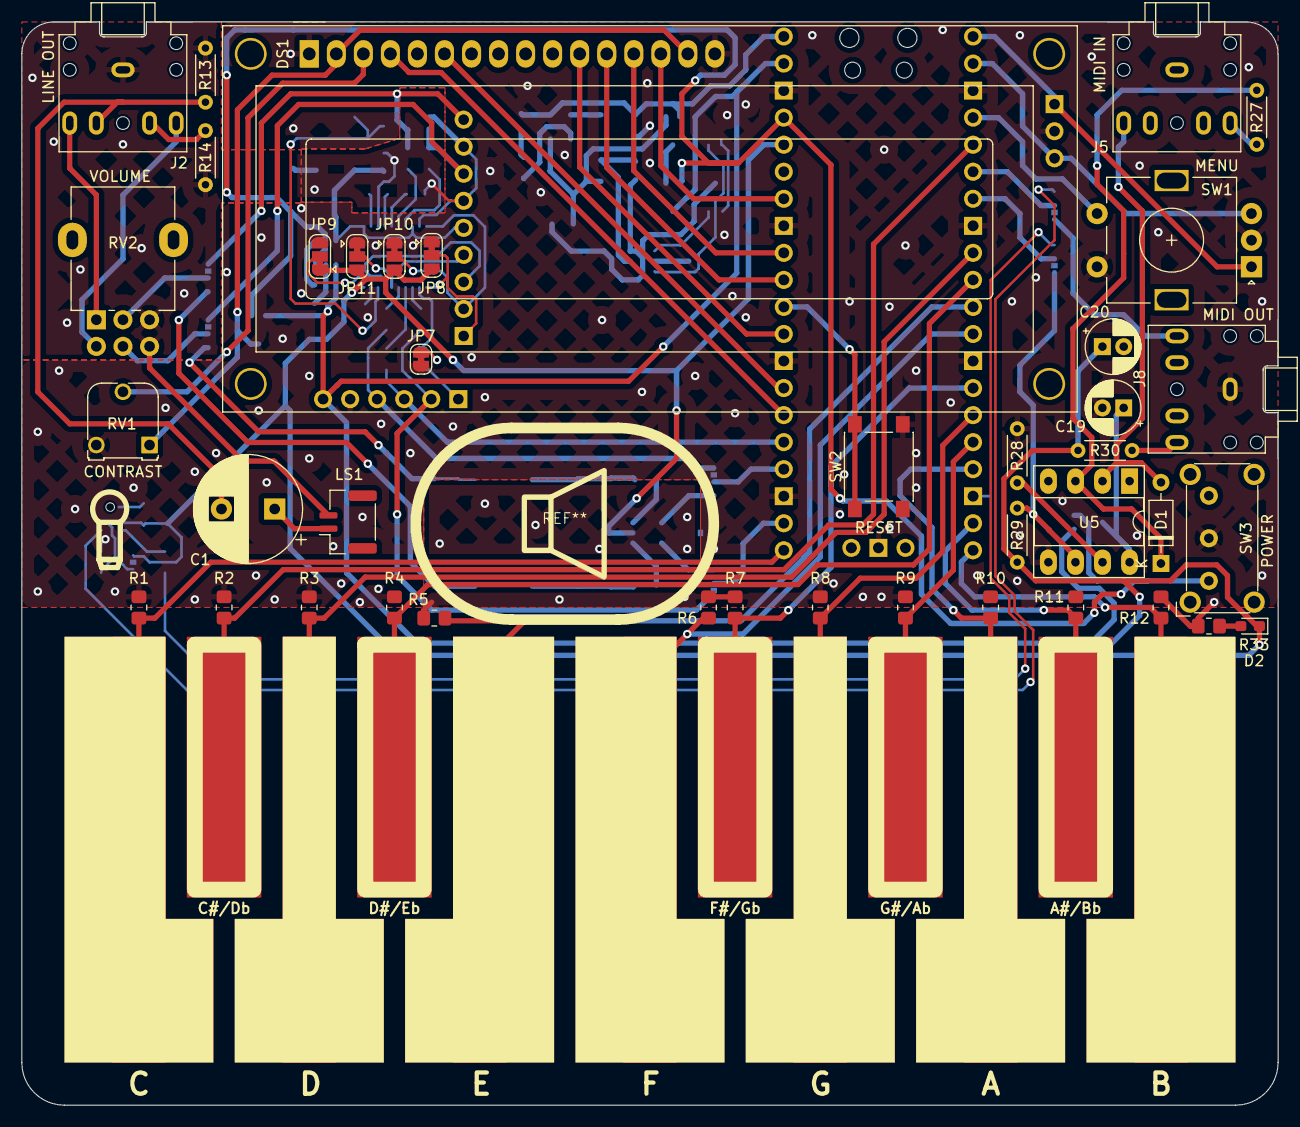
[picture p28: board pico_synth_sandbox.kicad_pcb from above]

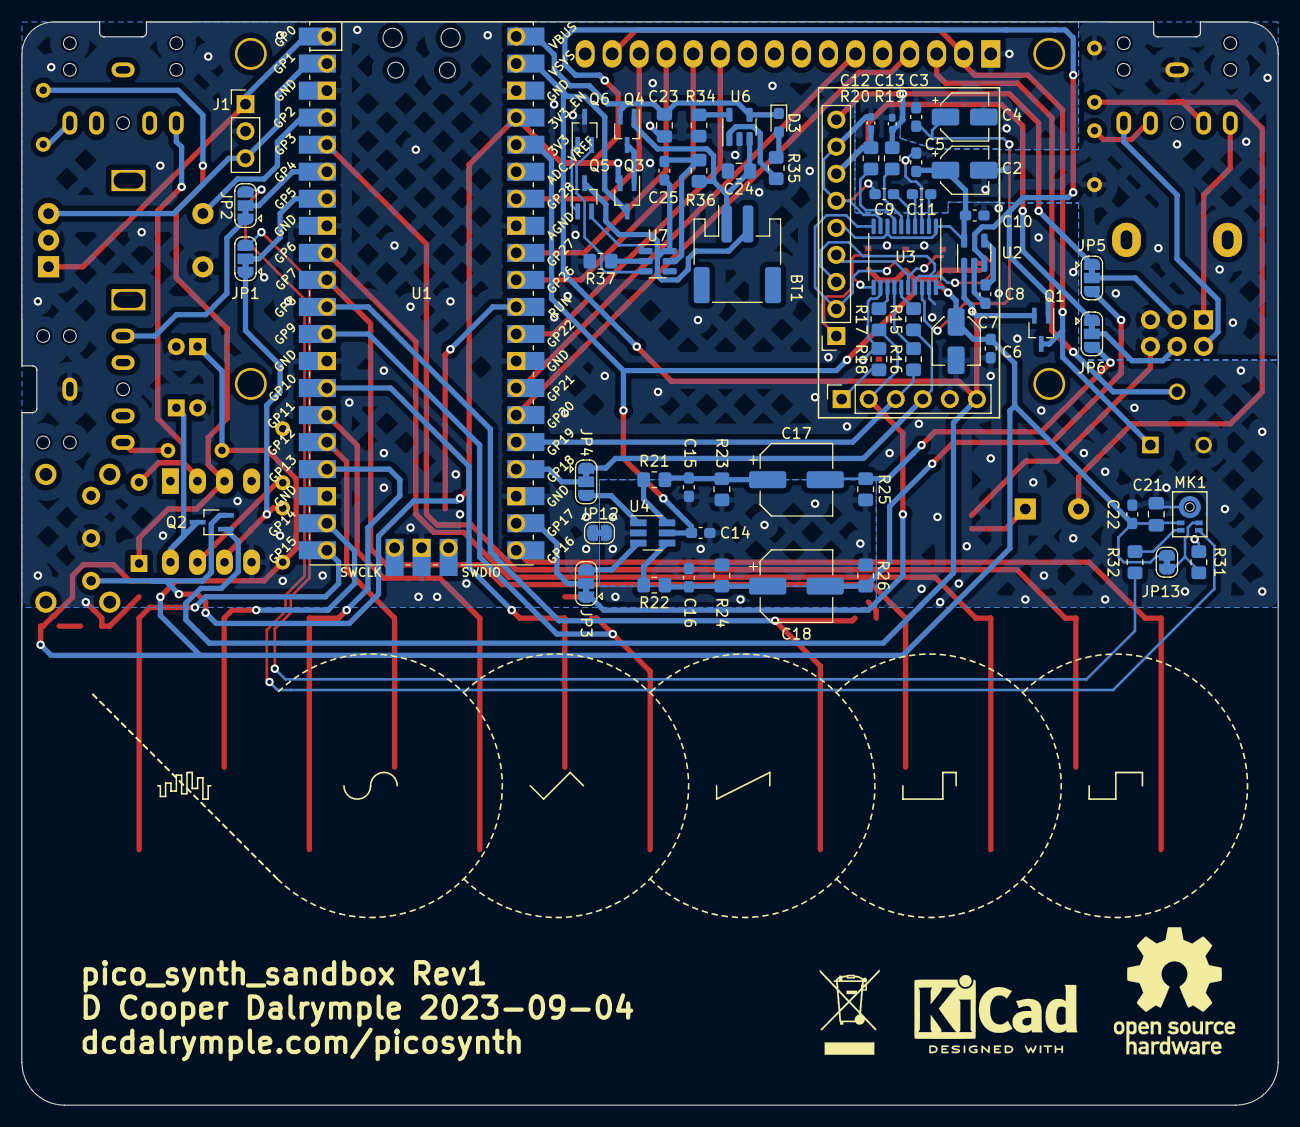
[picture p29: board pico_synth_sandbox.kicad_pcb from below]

Board: 2 copper layers, 118.0 x 101.7 mm, 118 parts (66 on the bottom side), 96 nets.

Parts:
BT1: LiPo Battery; JST_PH_S2B-PH-SM4-TB_1x02-1MP_P2.00mm_Horizontal
C1: 220uF; CP_Radial_D10.0mm_P5.00mm
C2, C4, C7: 10uF; CP_Elec_4x5.4
C3, C5, C6, C14, C15, C16, C22, C25: 0.1uF; C_0603_1608Metric_Pad1.08x0.95mm_HandSolder
C8: 470pF; C_0603_1608Metric_Pad1.08x0.95mm_HandSolder
C9, C10, C11: 2.2uF; C_0603_1608Metric_Pad1.08x0.95mm_HandSolder
C12, C13: 2.2nF; C_0402_1005Metric_Pad0.74x0.62mm_HandSolder
C17, C18: 47uF; CP_Elec_6.3x5.7
C19, C20: 1uF; CP_Radial_D5.0mm_P2.00mm
C21, C23, C24: 10uF; C_0805_2012Metric_Pad1.18x1.45mm_HandSolder
D1: 1N914; D_DO-35_SOD27_P7.62mm_Horizontal
D2: PWR; LED_0603_1608Metric_Pad1.05x0.95mm_HandSolder
D3: CHRG; LED_0603_1608Metric_Pad1.05x0.95mm_HandSolder
DS1: WC1602A
J1: UART0; PinHeader_1x03_P2.54mm_Vertical
J2: LINEOUT; Jack_3.5mm_CUI_SJ1-3525N_Horizontal
J3: M-BUS; PinSocket_1x06_P2.54mm_Vertical
J4: A-BUS; PinSocket_1x09_P2.54mm_Vertical
J5: MIDIIN; Jack_3.5mm_CUI_SJ1-3525N_Horizontal
J8: MIDIOUT; Jack_3.5mm_CUI_SJ1-3525N_Horizontal
JP1: PDMDAT; SolderJumper-3_P1.3mm_Bridged12_RoundedPad1.0x1.5mm
JP2: PDMCLK; SolderJumper-3_P1.3mm_Bridged12_RoundedPad1.0x1.5mm
JP3: I2SPWML; SolderJumper-3_P1.3mm_Bridged12_RoundedPad1.0x1.5mm
JP4: I2SPWMR; SolderJumper-3_P1.3mm_Bridged12_RoundedPad1.0x1.5mm
JP5: ALJP; SolderJumper-3_P1.3mm_Bridged12_RoundedPad1.0x1.5mm
JP6: ARJP; SolderJumper-3_P1.3mm_Bridged12_RoundedPad1.0x1.5mm
JP7: SCK; SolderJumper-2_P1.3mm_Bridged_RoundedPad1.0x1.5mm
JP8: H1L; SolderJumper-3_P1.3mm_Bridged12_RoundedPad1.0x1.5mm
JP9: H3L; SolderJumper-3_P1.3mm_Bridged12_RoundedPad1.0x1.5mm
JP10: H2L; SolderJumper-3_P1.3mm_Bridged12_RoundedPad1.0x1.5mm
JP11: H4L; SolderJumper-3_P1.3mm_Bridged12_RoundedPad1.0x1.5mm
JP12: SolderJumper_2_Bridged; SolderJumper-2_P1.3mm_Bridged_RoundedPad1.0x1.5mm
JP13: PDMSEL; SolderJumper-2_P1.3mm_Bridged_RoundedPad1.0x1.5mm
LS1: Speaker; JST_GH_SM02B-GHS-TB_1x02-1MP_P1.25mm_Horizontal
MK1: IM69D130; Infineon_PG-LLGA-5-1
Q1, Q2, Q3, Q5, Q6: NMOS; SOT-323_SC-70_Handsoldering
Q4: PMOS; SOT-323_SC-70_Handsoldering
R1, R2, R3, R4, R5, R6, R7, R8, R9, R10, R11, R12: 1M; R_0805_2012Metric_Pad1.20x1.40mm_HandSolder
R13, R14: 10k; R_Axial_DIN0204_L3.6mm_D1.6mm_P5.08mm_Horizontal
R15, R16, R17, R18: 22; R_0805_2012Metric_Pad1.20x1.40mm_HandSolder
R19, R20: 470; R_0805_2012Metric_Pad1.20x1.40mm_HandSolder
R21, R22: 220; R_0805_2012Metric_Pad1.20x1.40mm_HandSolder
R23, R24, R32: 100; R_0805_2012Metric_Pad1.20x1.40mm_HandSolder
R25, R26: 1.8k; R_0805_2012Metric_Pad1.20x1.40mm_HandSolder
R27, R30: 220; R_Axial_DIN0204_L3.6mm_D1.6mm_P5.08mm_Horizontal
R28: 4.7k; R_Axial_DIN0204_L3.6mm_D1.6mm_P5.08mm_Horizontal
R29: 470; R_Axial_DIN0204_L3.6mm_D1.6mm_P5.08mm_Horizontal
R31: 10k; R_0805_2012Metric_Pad1.20x1.40mm_HandSolder
R33, R35: 1k; R_0805_2012Metric_Pad1.20x1.40mm_HandSolder
R34: 4.7k; R_0805_2012Metric_Pad1.20x1.40mm_HandSolder
R36: 330; R_0805_2012Metric_Pad1.20x1.40mm_HandSolder
R37: 2.7k; R_0805_2012Metric_Pad1.20x1.40mm_HandSolder
RV1: 10k; Potentiometer_Runtron_RM-065_Vertical
RV2: 100k; Potentiometer_Alpha_RD902F-40-00D_Dual_Vertical
SW1: RotaryEncoder_Switch; RotaryEncoder_Alps_EC11E-Switch_Vertical_H20mm
SW2: RESET; SW_Push_1P1T_NO_6x6mm_H9.5mm
SW3: PWR_EN; SW_E-Switch_EG1224_SPDT_Angled
TP1: C; CapKeysWhiteLeft
TP2: C#/Db; CapKeysBlack
TP3: D; CapKeysWhiteMiddle
TP4: D#/Eb; CapKeysBlack
TP5: E; CapKeysWhiteRight
TP6: F; CapKeysWhiteLeft
TP7: F#/Gb; CapKeysBlack
TP8: G; CapKeysWhiteMiddle
TP9: G#/Ab; CapKeysBlack
TP10: A; CapKeysWhiteMiddle
TP11: A#/Bb; CapKeysBlack
TP12: B; CapKeysWhiteRight
U1: Pico; RPi_Pico_SMD_TH
U2: MIC5219-3.3YM5; SOT-23-5
U3: PCM5102A; TSSOP-20_4.4x6.5mm_P0.65mm
U4: 74AUC2G34; SOT-23-6_Handsoldering
U5: 6N138; DIP-8_W7.62mm_Socket_LongPads
U6: MCP73831-5-OT; SOT-23-5
U7: AP9101CK6; SOT-23-6

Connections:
+3.3V: C6.1, C7.1, C14.1, C20.1, C21.1, C22.1, D2.1 (K), JP8.3 (B), JP9.1 (A), JP10.3 (B), JP11.3 (B), JP13.2 (B), MK1.2 (VDD), R29.1, R30.1, U1.36 (3V3), U3.20 (DVDD), U4.5 (VCC)
+3.3VA: C2.1, C5.1, C10.1, J4.5, U2.5 (OUT), U3.1 (CPVDD), U3.8 (AVDD)
+BATT: BT1.1 (+), C24.1, Q4.1 (D), R36.1, U6.3 (V_{BAT})
-BATT: BT1.2 (-), C25.2, Q5.3 (S), U7.6 (VSS)
/1602D4: DS1.14 (D7), U1.34 (GPIO28_ADC2)
/1602D5: DS1.13 (D6), U1.32 (GPIO27_ADC1)
/1602D6: DS1.12 (D5), U1.31 (GPIO26_ADC0)
/1602D7: DS1.11 (D4), U1.29 (GPIO22)
/1602EN: DS1.6 (E), U1.27 (GPIO21)
/1602RS: DS1.4 (RS), U1.26 (GPIO20)
/ENCA: J1.1, SW1.A, U1.1 (GPIO0)
/ENCB: J1.3, SW1.B, U1.2 (GPIO1)
/I2S Audio/DEMP: J4.2, JP10.2 (C), U3.10 (DEMP)
/I2S Audio/FLT: J4.1, JP8.2 (C), U3.11 (FLT)
/I2S Audio/FMT: J4.4, JP11.2 (C), U3.16 (FMT)
/I2S Audio/LDOO: C3.1, C4.1, U3.18 (LDOO)
/I2S Audio/SCK: J3.1, R18.1
/I2S Audio/XSMT: J4.3, JP9.2 (C), U3.17 (XSMT)
/SWA: SW1.S1, U1.4 (GPIO2)
/TPAD1: R1.1, TP1.1, U1.21 (GPIO16)
/TPAD2: R2.1, TP2.1, U1.5 (GPIO3)
/TPAD3: R3.1, TP3.1, U1.9 (GPIO6)
/TPAD4: R4.1, TP4.1, U1.10 (GPIO7)
/TPAD5: R5.1, TP5.1, U1.11 (GPIO8)
/TPAD6: R6.1, TP6.1, U1.12 (GPIO9)
/TPAD7: R7.1, TP7.1, U1.14 (GPIO10)
/TPAD8: R8.1, TP8.1, U1.15 (GPIO11)
/TPAD9: R9.1, TP9.1, U1.16 (GPIO12)
/TPAD10: R10.1, TP10.1, U1.17 (GPIO13)
/TPAD11: R11.1, TP11.1, U1.19 (GPIO14)
/TPAD12: R12.1, TP12.1, U1.20 (GPIO15)
GND: C3.2, C4.2, C6.2, C7.2, C8.2, C10.2, C19.2, C20.2, C21.2, C22.2, C23.2, C24.2, DS1.1 (VSS), DS1.5 (R/W), DS1.16 (LED(-)), J1.2, J3.5, J8.S, JP7.1 (A), JP8.1 (A), JP9.3 (B), JP10.1 (A), JP11.1 (A), JP12.1 (A), MK1.5 (GND), Q6.3 (S), R1.2, R2.2, R3.2, R4.2, R5.2, R6.2, R7.2, R8.2, R9.2, R10.2, R11.2, R12.2, R28.2, R31.2, R33.2, R34.2, R37.2, RV1.3, SW1.C, SW1.S2, SW2.2, SW3.2 (B), U1.3 (GND), U1.8 (GND), U1.13 (GND), U1.18 (GND), U1.23 (GND), U1.28 (GND), U1.33 (AGND), U1.38 (GND), U1.42 (GND), U2.2 (GND), U3.19 (DGND), U5.5 (GND), U6.2 (V_{SS})
GNDA: C2.2, C5.2, C9.2, C12.2, C13.2, J2.S, J4.6, J4.8, LS1.2, R13.2, R14.2, RV2.3, RV2.6, U3.3 (CPGND), U3.9 (AGND)
GNDD: C14.2, C15.1, C16.1, JP12.2 (B), R23.1, R24.1, R25.1, R26.1, U4.2 (GND)
I2SAL: C13.1, J4.9, JP5.1 (A), R19.1
I2SAR: C12.1, J4.7, JP6.1 (A), R20.1
I2SCLK: J3.2, JP3.1 (A), R17.1
I2SDAT: J3.3, R16.1, U1.25 (GPIO19)
I2SWS: J3.4, JP4.1 (A), R15.1
MICCLK: JP2.3 (B), MK1.3 (CLOCK)
MICDAT: JP1.3 (B), R32.2
MIDIRX: JP1.1 (A), R29.2, U5.6 (VO2)
MIDITX: J8.T, JP2.1 (A)
unnamed: C1.1, LS1.1
unnamed: C1.2, J2.TN, R13.1
unnamed: C15.2, C17.1, R21.1, R23.2
unnamed: C16.2, C18.1, R22.1, R24.2
unnamed: D1.2 (A), J5.T, U5.2 (C1)
unnamed: D1.1 (K), R27.2, U5.3 (C2)
unnamed: D2.2 (A), R33.1
unnamed: D3.2 (A), R35.1
unnamed: DS1.2 (VDD), DS1.15 (LED(+)), Q1.3 (S), RV1.1
unnamed: DS1.3 (VO), RV1.2
unnamed: J2.R, RV2.4
unnamed: J2.RN, R14.1
unnamed: J2.T, RV2.1
unnamed: J5.R, R27.1
unnamed: J8.R, R30.2
unnamed: JP1.2 (C), U1.7 (GPIO5)
unnamed: JP2.2 (C), U1.6 (GPIO4)
unnamed: JP3.2 (C), U1.22 (GPIO17)
unnamed: JP4.2 (C), U1.24 (GPIO18)
unnamed: JP5.2 (C), RV2.2
unnamed: JP6.2 (C), RV2.5
unnamed: JP7.2 (B), R18.2, U3.12 (SCK)
unnamed: JP13.1 (A), MK1.4 (SELECT), R31.1
unnamed: MK1.1 (DATA), R32.1
unnamed: C19.1, Q2.3 (S), U5.8 (VCC)
unnamed: Q5.1 (D), Q6.1 (D)
unnamed: Q5.2 (G), U7.1 (DO)
unnamed: Q6.2 (G), U7.3 (CO)
unnamed: R21.2, U4.6
unnamed: R22.2, U4.4
unnamed: C8.1, U2.4 (BP)
unnamed: R17.2, U3.13 (BCK)
unnamed: C11.2, U3.4 (CAPM)
unnamed: C11.1, U3.2 (CAPP)
unnamed: R16.2, U3.14 (DIN)
unnamed: R15.2, U3.15 (LRCK)
unnamed: R19.2, U3.6 (OUTL)
unnamed: R20.2, U3.7 (OUTR)
unnamed: C9.1, U3.5 (VNEG)
unnamed: R28.1, U5.7 (VO1)
unnamed: R34.1, U6.5 (PROG)
unnamed: R35.2, U6.1 (STAT)
unnamed: C25.1, R36.2, U7.5 (VDD)
unnamed: R37.1, U7.2 (VM)
PWMAL: C18.2, JP5.3 (B), R26.2
PWMAR: C17.2, JP6.3 (B), R25.2
PWMDL: JP3.3 (B), U4.3
PWMDR: JP4.3 (B), U4.1
PWR_EN: Q1.1 (D), Q2.2 (G), Q3.2 (G), SW3.1 (A), U1.37 (3V3_EN), U2.3 (EN)
RUN: SW2.1, U1.30 (RUN)
VBUS: C23.1, D3.1 (K), Q4.2 (G), U1.40 (VBUS), U6.4 (V_{DD})
VSYS: J3.6, Q1.2 (G), Q2.1 (D), Q3.3 (S), U1.39 (VSYS), U2.1 (IN)
VSYS&VBAT: Q3.1 (D), Q4.3 (S)

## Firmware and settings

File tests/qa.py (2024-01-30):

import board
import adafruit_character_lcd.character_lcd as characterlcd
from digitalio import DigitalInOut, Direction, Pull
from rotaryio import IncrementalEncoder
from adafruit_debouncer import Debouncer
import rotaryio
import touchio
import audiobusio
import audiomixer
import synthio
import busio
import adafruit_midi
from adafruit_midi.note_off import NoteOff
from adafruit_midi.note_on import NoteOn

# Character LCD
lcd_rs = DigitalInOut(board.GP7)
lcd_en = DigitalInOut(board.GP6)
lcd_d4 = DigitalInOut(board.GP22)
lcd_d5 = DigitalInOut(board.GP26)
lcd_d6 = DigitalInOut(board.GP27)
lcd_d7 = DigitalInOut(board.GP28)
lcd = characterlcd.Character_LCD_Mono(lcd_rs, lcd_en, lcd_d4, lcd_d5, lcd_d6, lcd_d7, 16, 2)

def lcd_print(name, value):
    lcd.clear()
    lcd.message = name + "\n" + value

lcd.cursor = False
lcd.blink = False
lcd_print("PicoSynthSandbox", "Rev2 2024-01-25")

# Encoder
def get_button(pin):
    input = DigitalInOut(pin)
    input.direction = Direction.INPUT
    input.pull = Pull.UP
    return Debouncer(input)

button = (
    get_button(board.GP13),
    get_button(board.GP18)
)
encoder = (
    IncrementalEncoder(board.GP12, board.GP11),
    IncrementalEncoder(board.GP17, board.GP16)
)
last_position = [encoder[0].position, encoder[1].position]

def update_encoders():
    for i in range(2):
        current_position = encoder[i].position
        if current_position - last_position[i] != 0:
            lcd_print("Encoder {:d}".format(i+1), str(current_position))
        last_position[i] = current_position

        button[i].update()
        if button[i].fell:
            lcd_print("Encoder {:d}".format(i+1), "Press")
        if button[i].rose:
            lcd_print("Encoder {:d}".format(i+1), "Release")

# MIDI
uart = busio.UART(board.GP4, board.GP5, baudrate=31250, timeout=0.001)
midi = adafruit_midi.MIDI(
    midi_in=uart,
    in_channel=0,
    midi_out=uart,
    out_channel=0
)

# Audio
audio = audiobusio.I2SOut(
    bit_clock=board.GP19,
    word_select=board.GP20,
    data=board.GP21
)
mixer = audiomixer.Mixer(
    channel_count=2,
    sample_rate=44100,
    buffer_size=2048
)
audio.play(mixer)
synth = synthio.Synthesizer(
    channel_count=2,
    sample_rate=44100,
    envelope=synthio.Envelope(
        attack_time=0.025,
        attack_level=0.8,
        decay_time=0.025,
        sustain_level=0.4,
        release_time=0.2
    )
)
mixer.voice[0].play(synth)
mixer.voice[0].level = 0.5

# Keyboard
sdo = DigitalInOut(board.GP14)
sdo.direction = Direction.INPUT
sdo.pull = Pull.UP

scl = DigitalInOut(board.GP15)
scl.direction = Direction.OUTPUT

keyboard_data = 0

class Key:
    def __init__(self, name, index):
        self.name = name
        self.index = index
        self.bit = 1 << index
        self.switch = Debouncer(self.read)
    def read(self):
        global keyboard_data
        return bool(keyboard_data & self.bit)
    def get_notenum(self):
        return 59+self.index
    def update(self):
        self.switch.update()
        if self.switch.rose:
            lcd_print("Keyboard", self.name + " Pressed")
            synth.press(self.get_notenum())
            midi.send(NoteOn(self.get_notenum(), 20))
        if self.switch.fell:
            lcd_print("Keyboard", self.name + " Released")
            synth.release(self.get_notenum())
            midi.send(NoteOff(self.get_notenum(), 0))

keys = [
    Key("B", 0),
    Key("C", 1),
    Key("C#", 2),
    Key("D", 3),
    Key("D#", 4),
    Key("E", 5),
    Key("F", 6),
    Key("F#", 7),
    Key("G", 8),
    Key("G#", 9),
    Key("A", 10),
    Key("A#", 11),
    Key("B", 12),
    Key("C", 13),
    Key("C#", 14),
    Key("D", 15)
]

def update_keyboard():
    global keyboard_data
    keyboard_data = 0
    scl.value = False
    for i in range(16):
        scl.value = True
        if sdo.value:
            keyboard_data |= (1 << i)
        scl.value = False
    scl.value = True
    for key in keys:
        key.update()

# Main Loop

while True:
    update_encoders()
    update_keyboard()
    
    msg = midi.receive()
    if msg is not None:
        if isinstance(msg, NoteOn):
            if msg.velocity > 0:
                synth.press(msg.note)
            else:
                synth.release(msg.note)
        elif isinstance(msg, NoteOff):
            synth.release(msg.note)

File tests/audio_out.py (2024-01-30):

import audiocore
import audiobusio
import board
import array
import time
import math

sample_rate = 22050
length = sample_rate // 440
sine_wave = array.array("H", [0] * length)
for i in range(length):
    sine_wave[i] = int(math.sin(math.pi * 2 * i / length) * (2 ** 15) + 2 ** 15)
sine_wave = audiocore.RawSample(sine_wave, sample_rate=sample_rate)

dac = audiobusio.I2SOut(
    bit_clock=board.GP19,
    word_select=board.GP20,
    data=board.GP21
)

while True:
    dac.play(sine_wave, loop=True)
    time.sleep(0.5)
    dac.stop()
    time.sleep(0.5)

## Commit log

2023-11-14 Migrated from `pico_synth_sandbox` repository.
    [C0603.step, C1005.step, C2012.step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]
2023-11-15 Added CircuitPython test for TonTouch TTP229 IC.
2024-01-01 Revision 2 of schematic and pcb.
    [PJ320A.SLDPRT, PJ320D-Pin-B.SLDPRT, PJ320D-Pin.SLDPRT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]
2024-01-02 Added additional 3d models to pcb.
    [MK-23D38.FCStd, MK-23D38.step, MK-23D38.stl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]
2024-01-02 Rev2 renders and schematic.
2024-01-02 Rev1 3d printed case.
    [pico_synth_sandbox-Rev1-Bottom_Full_FootIndents.stl, pico_synth_sandbox-Rev1-Button.stl]
2024-01-02 Fixed I2S global label direction in schematic.
    [pico_synth_sandbox.kicad_sch]
2024-01-10 Improved capacitor spacing around battery connector.
2024-01-10 Battery orientation indicators added to silkscreen.
2024-01-16 Fixed character lcd data pin references.
    [pico_synth_sandbox.kicad_sch]
2024-01-16 Updated rotary encoder test for Rev2.
2024-01-17 Simple stencil jig (rev2)
    [pico_synth_sandbox-StencilJig.FCStd, pico_synth_sandbox-StencilJig.stl]
2024-01-17 Removed unnecessary tests and updated pin assignments.
2024-01-17 Various minor schematic updates.
    [audio_out.kicad_sch, battery.kicad_sch, i2s_adc.kicad_sch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]
2024-01-30 Updated pin allocations for more CircuitPython tests.
2024-02-06 3D printed case design for Rev2.
    [pico_synth_sandbox-Rev2-Bottom.stl, pico_synth_sandbox-Rev2-LcdHeader.stl, pico_synth_sandbox-Rev2-Switch.stl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]
2024-02-21 Minor update to ADC connection.
    [i2s_adc.kicad_sch, pico_synth_sandbox.kicad_sch]
2024-09-08 Updated to Kicad v8.0.
    [audio_out.kicad_sch, battery.kicad_sch, i2s_adc.kicad_sch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]
2024-09-08 Fixed error with TTP229BSF power input.
    [keyboard.kicad_sch]

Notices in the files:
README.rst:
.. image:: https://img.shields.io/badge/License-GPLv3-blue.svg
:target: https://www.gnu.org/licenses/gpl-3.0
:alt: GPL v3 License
